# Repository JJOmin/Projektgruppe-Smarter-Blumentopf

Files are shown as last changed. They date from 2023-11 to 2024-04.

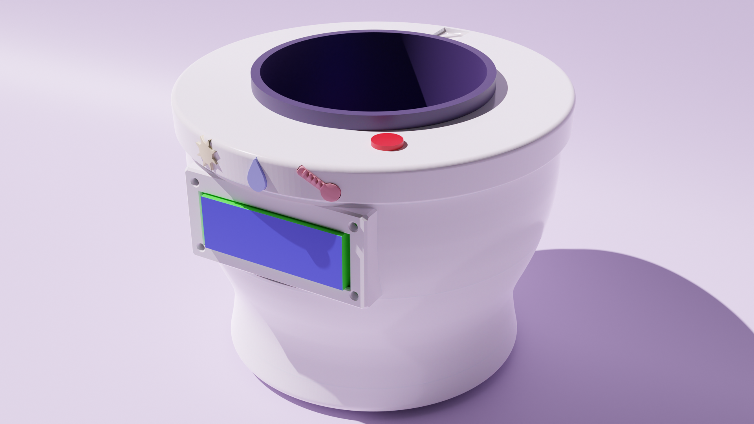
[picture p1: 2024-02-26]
3dModel/gerendert.png

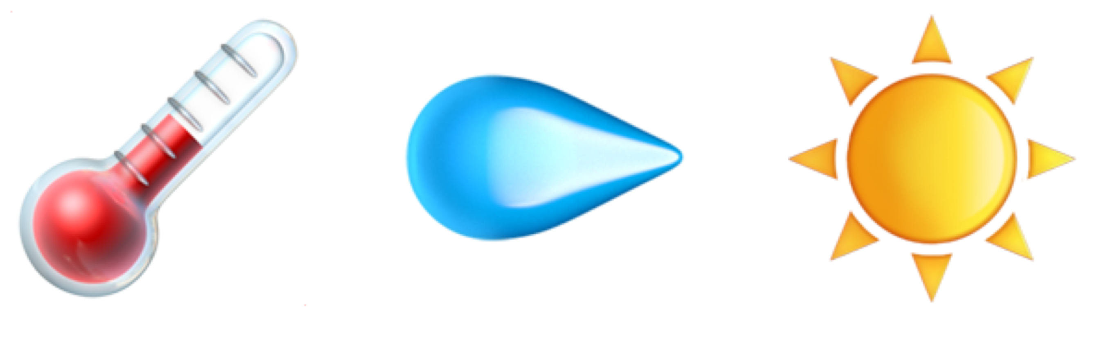
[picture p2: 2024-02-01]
3dModel/Bildschirmfoto 2024-01-30 um 16.26.23.png

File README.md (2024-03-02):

# Projektgruppe-Smarter-Blumentopf

**Projektbeschreibung:** Dieses Projekt konzentriert sich auf die Entwicklung eines intelligenten Blumentopfes, der durch eine Begleit-App gesteuert wird. Das Ziel ist es, eine nachhaltige und effiziente Bewässerung für Pflanzen zu ermöglichen, während gleichzeitig verschiedene Sensoren die Bedingungen der Pflanze überwachen. Programmablauf [hier](https://github.com/JJOmin/Projektgruppe-Smarter-Blumentopf/blob/44800ab2f6299ea2662f18130984cc1ef9804382/ESP32/README.md)

**Gruppenmitglieder:** 
[@Leo](https://github.com/JJOmin) [@Anna](https://github.com/Discovery1701A) [@Enis](https://github.com/NisVison) [@David](https://github.com/DaveBue) [@Sam](https://github.com/hystics)
  
## Guides
- ESP32 In Betriebnahme [hier](https://github.com/JJOmin/Projektgruppe-Smarter-Blumentopf/tree/c79d338f0dc577e0411f519bfa427959de9283d4/Guides)
  
## Programme
- Thonny IDE für MicroPython und ESP32 [hier](https://thonny.org/)
- Wokwi Simulation des ESP32 [hier](https://wokwi.com/projects/334090875207418452)
- Silicon Labs Treiber für USB to UART [hier](https://www.silabs.com/developers/usb-to-uart-bridge-vcp-drivers?tab=downloads)

## Sensoren Programmierung
  - **Simulation mit Wokwi [hier](https://github.com/JJOmin/Projektgruppe-Smarter-Blumentopf/tree/fa86ac6914044866652e3fb7bb85e3baa563d3ce/ESP32/Wokwi%20Simulation%20von%20Sensoren)**
  - **Courcecode [hier](https://github.com/JJOmin/Projektgruppe-Smarter-Blumentopf/tree/fa86ac6914044866652e3fb7bb85e3baa563d3ce/ESP32/Wokwi%20Simulation%20von%20Sensoren)**
    - Temperatursensor DS18B20 ([@Enis](https://github.com/NisVison))
    - Display ([@Anna](https://github.com/Discovery1701A) & [@Enis](https://github.com/NisVison))
    - Helligkeitssensor ([@Sam](https://github.com/hystics))
    - Bodenfeuchtigkeitssensor ([@Anna](https://github.com/Discovery1701A) & [@Leo](https://github.com/JJOmin))

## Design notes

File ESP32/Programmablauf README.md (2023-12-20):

# Programmablauf ESP32

## Setup
    - MVC Initialisierung
    - Aufbau der Wifi Connection
    - JSON Daten vom Server laden (db.json & prototyp.json) --> im Model speichern

## Programm-Loop (60 mal die Sekunde)

### Sensoren Intervall (alle 5 Sekunden)
    - Lesen der Sensorwerte
    - Vergleichen mit den Grenzwerten des gewählten Profils
        - ggfs. Status ändern --> Status Change Function (siehe unten)
    - Speichern der Messwerte im Model
        
### Server Intervall (nach 5 gemessenen Werte)
    - JSON Daten vom Server laden (prototyp.json) --> im Model speichern
        - ggfs. Änderungen für Name & Profil übernehmen
            - Bei Profiländerung: Neues Profil aus der db.json laden & Grenzwerte aktualisieren
    - Messwerte des Sensoren Intervalls mitteln
    - gemittelte Werte dem Log in der "prototyp.json" anhängen
    - "prototyp.json" auf dem Server überschreiben
    - Messwerte des Sensor Intervalls im Model zurücksetzen
    
### Button Pressed?
    - Wenn der Button gedrückt wird: Ausgabe der aktuellen Werte auf dem Display
    
### Status Change
    - LEDs Aktivieren/Deaktivieren
    - ggfs. Pumpe für kurze Zeit aktivieren
    - JSON Daten vom Server laden (prototyp.json)
    - Status in "prototyp.JSON" ändern
    - "prototyp.json" auf dem Server überschreiben

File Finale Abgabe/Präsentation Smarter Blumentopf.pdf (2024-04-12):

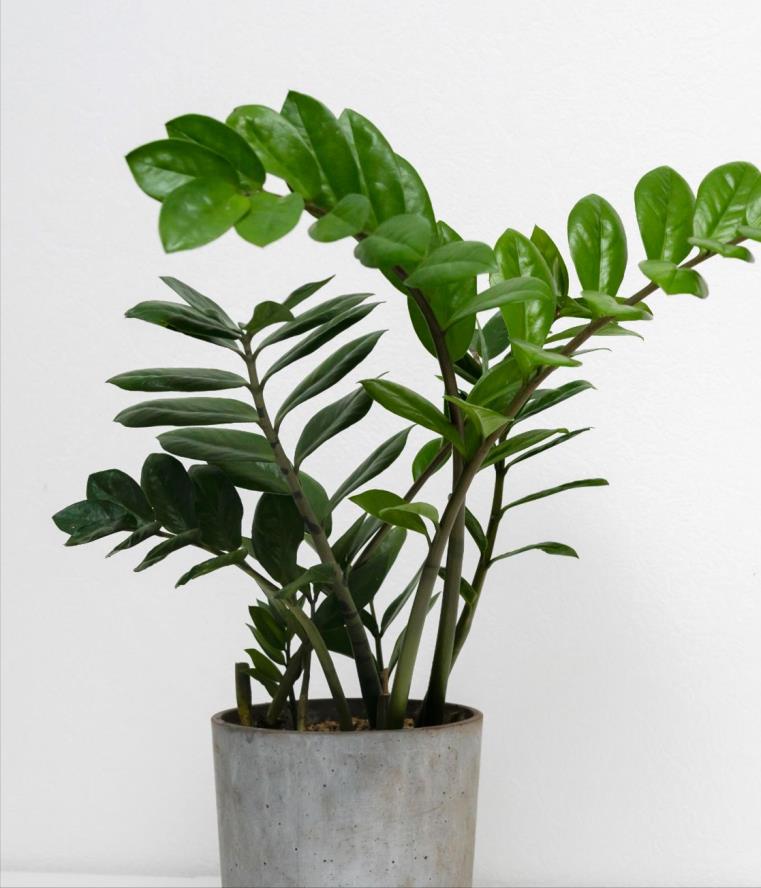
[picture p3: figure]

# Projektgruppe Interaktive Medien

beiProf. Dr. Maria Rauschenberger
ws 2023/24

Gruppe “Smarter Blumentopf”
von Enis Inep, David Bünnagel, Anna Rieckmann, Leonhard Tilly und Sarah Bokern

- Projektbeschreibung
- Ideenfindung
- HCD-Prozess – Aufbau, Umsetzung und Implementierung
- Umsetzung des Projektes
- Hardware
- Software
- Live-Demonstration
- Endergebnis
- Webinterface
- genutzte Arbeitsumgebungen
- Projektabschluss
- Quellen

## Präsentationsinhalt

## Projektbeschreibunginteraktive medien

- Konzeption und Entwicklung interaktiver
Medienprodukte
- Bedürfnisse und Verhaltensweisen von potenziellen Nutzern berücksichtigen
- Umsetzung mit HCD-Prozess
- Prototypgestaltung nach Interaktivität

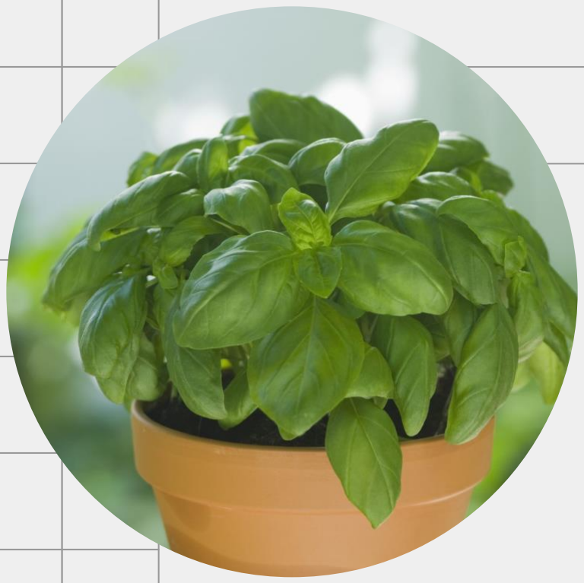
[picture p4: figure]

## Entstehung der grundidee

Ideenfindung

- Idee durch persönliche Erfahrungen: Basilikum stirbt sehr schnell
- Weiterführung: Was kann man dagegen tun? Gibt es eine technische Lösung?
- Folge: Recherche über "smarte" Blumentöpfe

## Recherche aktueller Projekte

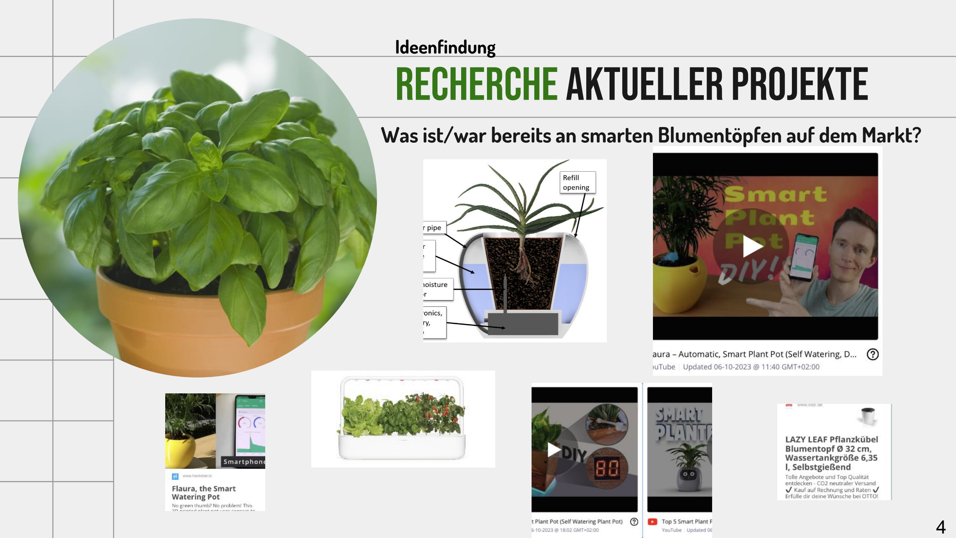
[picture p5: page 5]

Ideenfindung

Was ist/war bereits an smarten Blumentöpfen auf dem Markt?

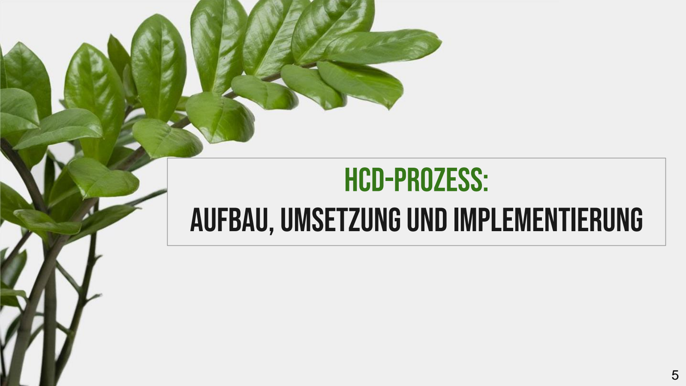
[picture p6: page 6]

## HCD-Prozess: aufbau, umsetzung und implementierung

## Erster entwurf: des blumentopfes

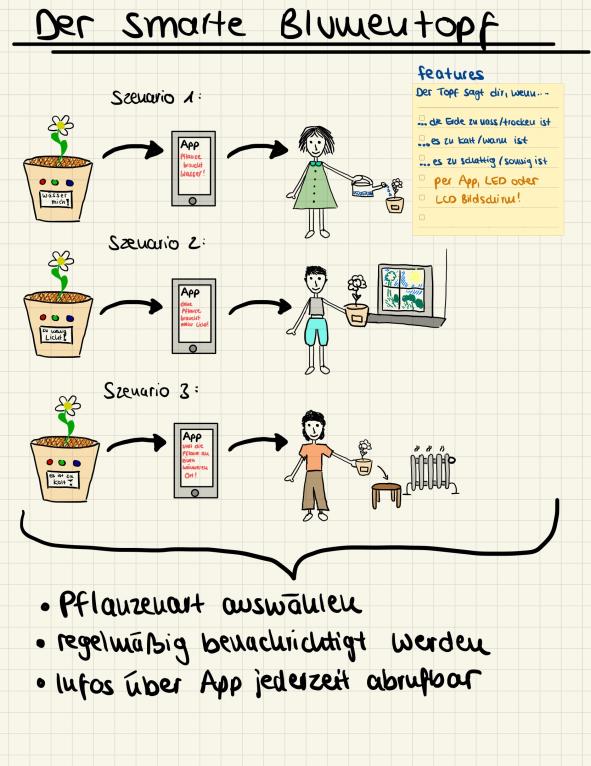
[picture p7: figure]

- Licht-, Temperatur- und Feuchtigkeitssensoren
- Auswählbare Pflanzenarten und Informationen zu idealen Haltungsverhältnissen
- Information durch App, LEDs und Display abrufbar

HCD-Prozess

## HCD-Prozess: aufbau und umsetzung

Aufbau der Semesterorganisation auf Grundlage des HCDs

Einteilung HCD in 2 große Phasen ("Teilabgabe" und "Endabgabe")

2 Fragebögen entworfen und ausgewertet

Auswertung, Implementierung, testen und erneute Befragung

## HCD-Prozess: UMFRAGE

Umfrage 1:
- Zielgruppe ist vergesslich
- Automatisierung (insbesondere Bewässerung)
- Steuerung über APP

Umfrage 2:
- LED Farben & Icons bestimmt
- Blinken vermeiden

Basierend auf Umfrage 1, Fragen 8/12/15/16/17, Umfrage 2, Fragen 5/6/7

- einfache Lösungen zur Haltung von Pflanzen
- Automatisierung, wenn niemand Zuhause ist
- Erinnerungen zur Pflege
- Erstellung von Pflanzenprofilen

## Persona grundprofil

profil
- Durchschnittsalter: 28 Jahre
- besitzt bereits Pflanzen
- berufstätig

charaktereigenschaften
- kann mit einfachen Problemen gut umgehen
- niedrige Frustrationstoleranz

wünsche

Stärken
- starke Technikaffinität

HCD-Prozess

- Vergesslichkeit

schwächen

9

## Entwicklungsziele

HCD-Prozess

- Effiziente Lösungen, die an den Nutzer angepasst sind

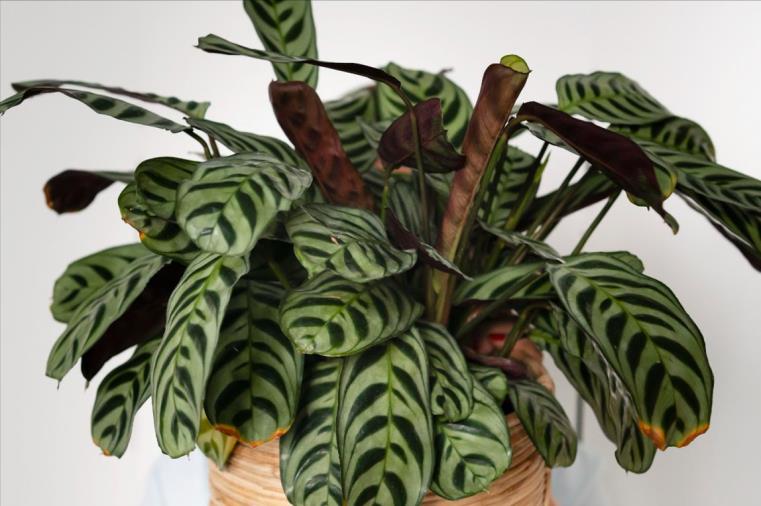
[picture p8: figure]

- Technische Unterstützung der Pflanzenpflege
- Anregung zur Verbesserung der Pflegeroutine
- Abnahme der Bewässerung

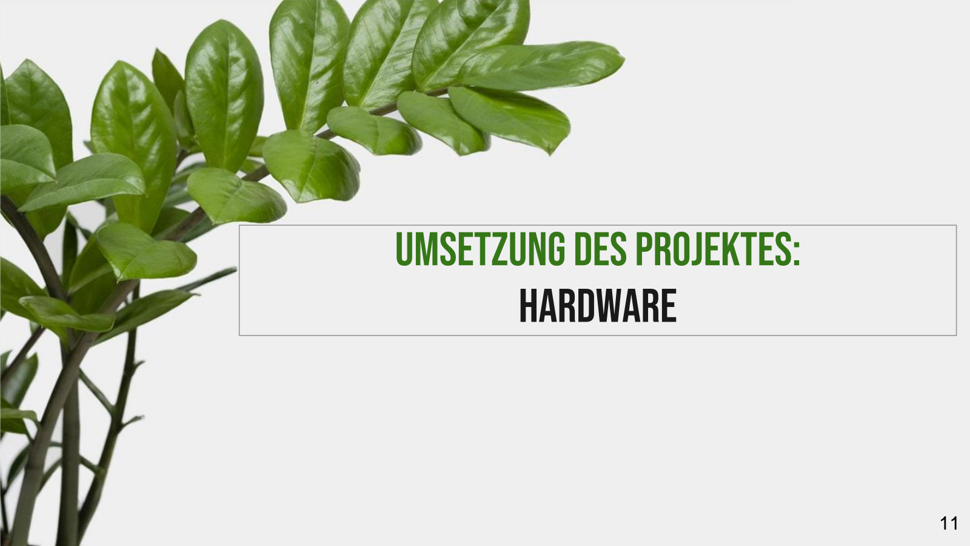
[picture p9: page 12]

## Umsetzung des projektes: hardware

## Hardware

Umsetzung des Projektes

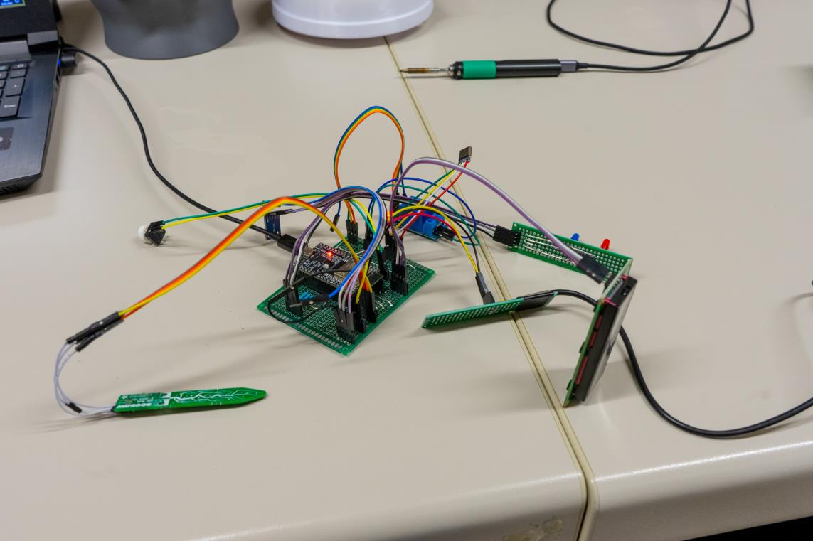
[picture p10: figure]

## Hardware-schaltplan

Umsetzung des Projektes

## Hardware

## - bauteile

Bauteile | Bezeichnung
Prozessor | ESP32 V2 WROOM
Bodenfeuchtigkeits -sensor | Adafruit STEMMA Soil Sensor -I2C Capacitive Moisture Sensor - JST PH 2mm
Temperatursensor | ds18b20
Helligkeitssensor | GY -302 BH1750
Display | DEBO LCD 16X2 BL
Relais | Songle sdr -05vdc -sl -c
Pumpe | PDM5 D916 5V

Umsetzung des Projektes

## Hardware - Blender

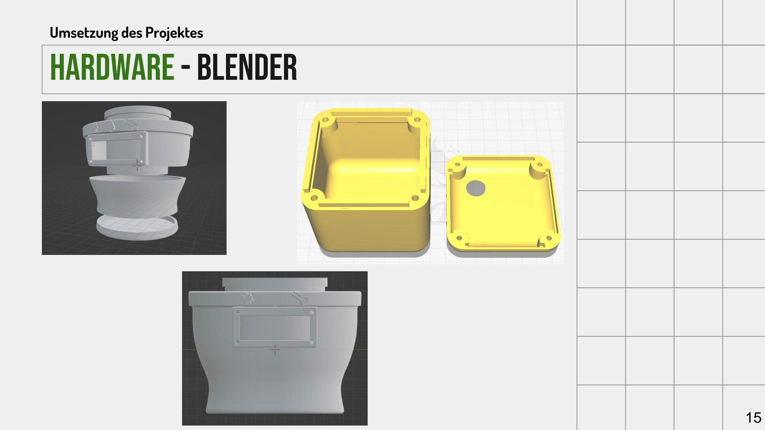
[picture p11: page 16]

Umsetzung des Projektes

## Hardware – Ausgabe

Umsetzung des Projektes

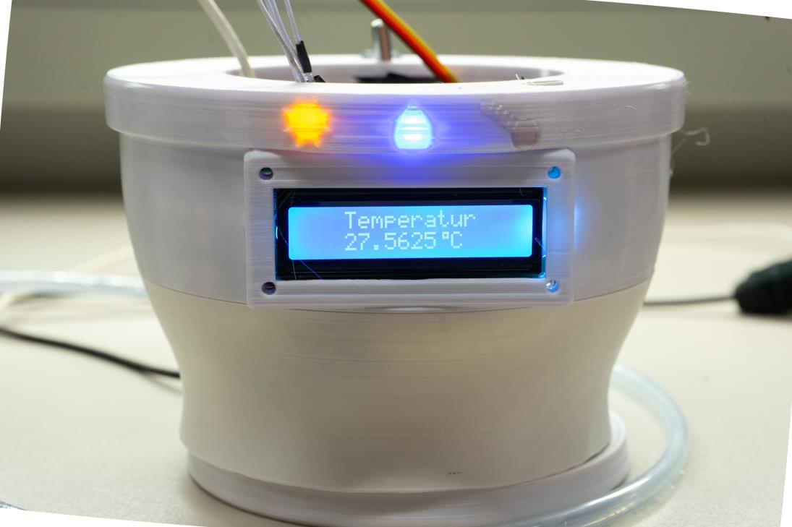
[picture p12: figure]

## Umsetzung des projektes: software

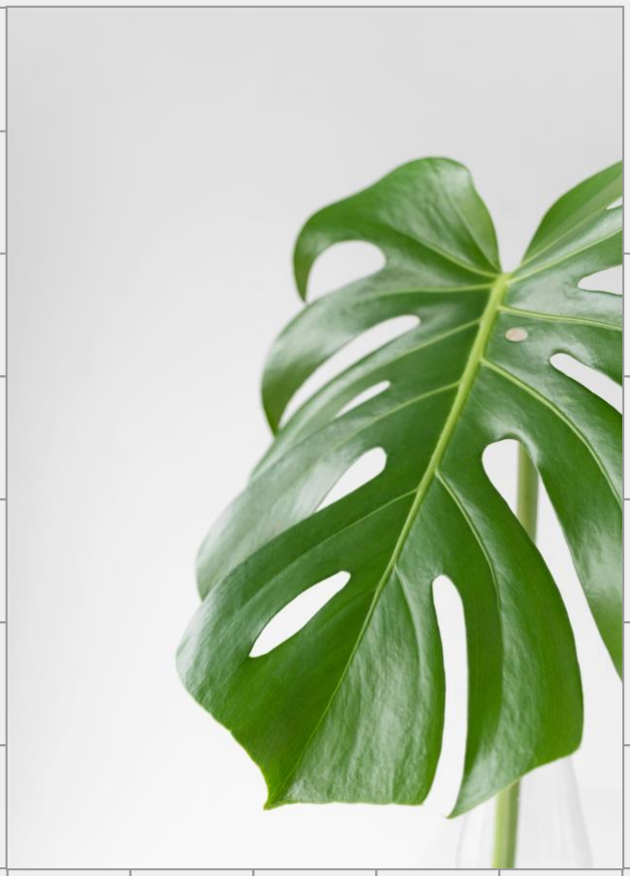
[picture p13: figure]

software • Arbeitsumgebung in Thonny • Umsetzung in Python, basierend

auf OOP

- Kommunikationsstruktur zwischen ESP, Hardware und
Webserver/Website?
- Aufbau des Programmes nach dem MVC

-Modell?

Umsetzung des Projektes

## Software: klassenstruktur

Umsetzung des Projektes

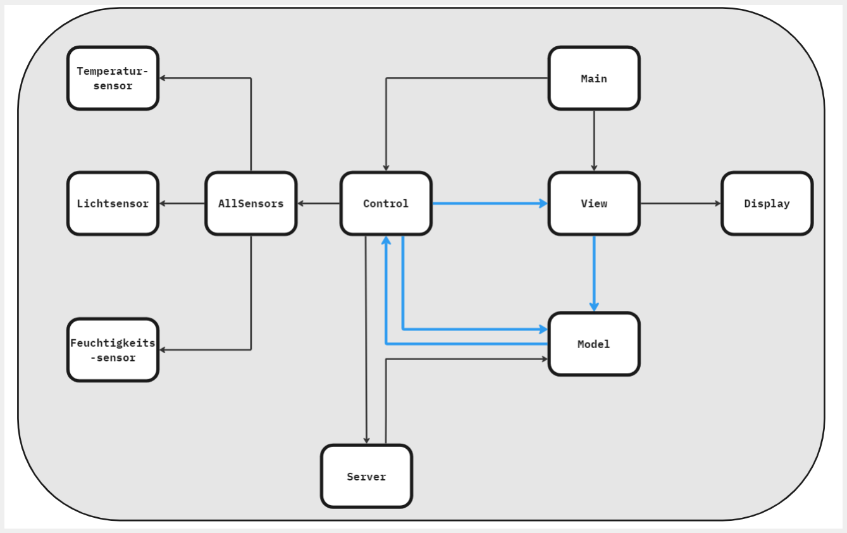
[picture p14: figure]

## Software: kommunikationsstruktur

Umsetzung des Projektes

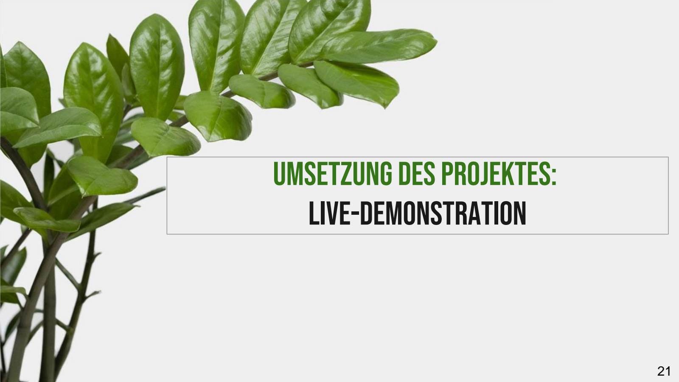
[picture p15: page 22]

## Umsetzung des projektes: Live-Demonstration

## Endergebis: der blumentopf

- Messung von Licht, Temperatur und Bodenfeuchtigkeit

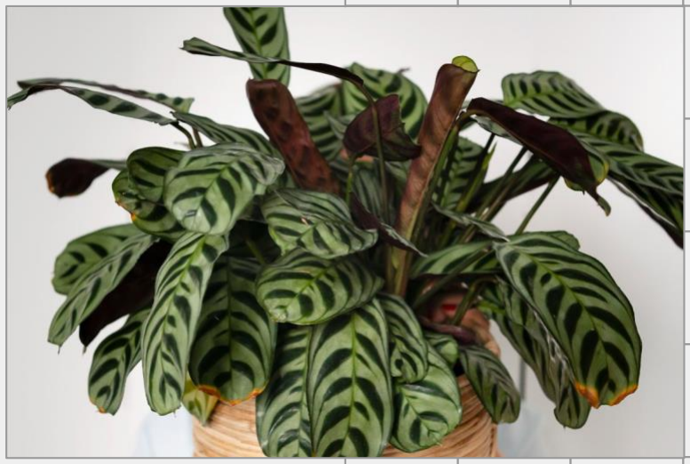
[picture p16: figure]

- Bewässerung
- Status LEDs
- Button zur Ausgabe auf dem Display
- Website zur Einsicht von Daten und zur Bearbeitung und Einstellungen von Profilen

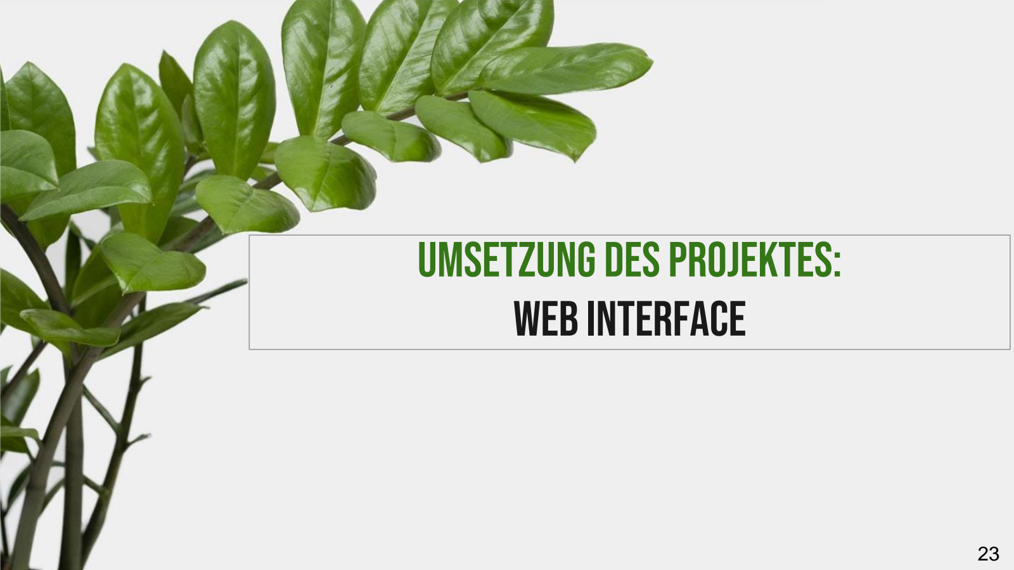
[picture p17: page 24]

## Umsetzung des projektes: Web interface

## Webinterface: browseransicht

Umsetzung des Projektes

## Webinterface: browseransicht

Umsetzung des Projektes

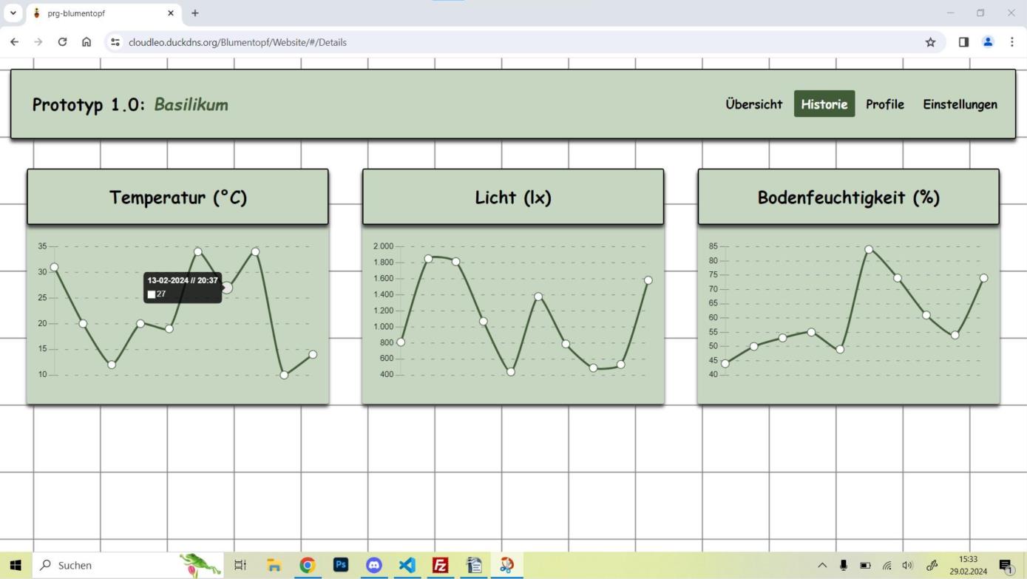
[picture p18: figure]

## Webinterface: browseransicht

Umsetzung des Projektes

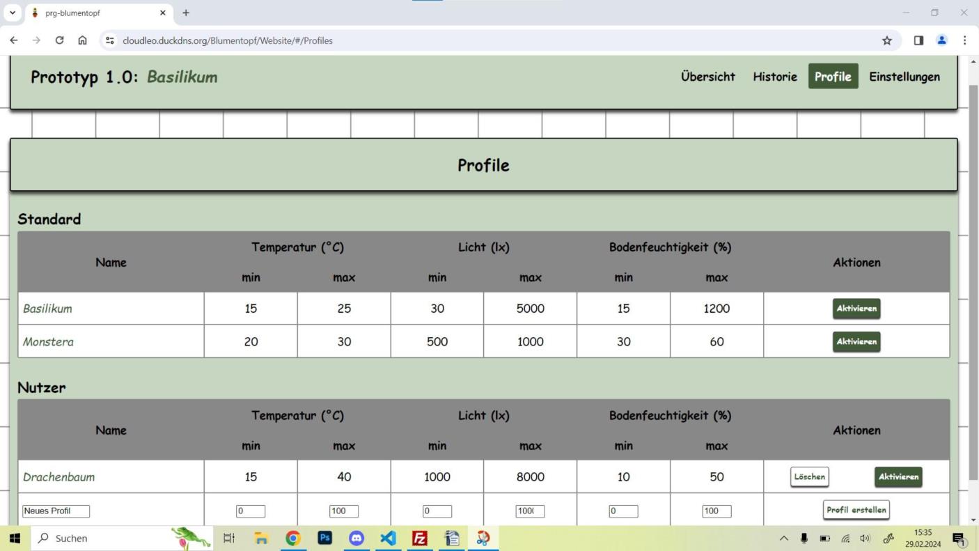
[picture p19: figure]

## Webinterface: browseransicht

Umsetzung des Projektes

## Webinterface: browseransicht

Umsetzung des Projektes

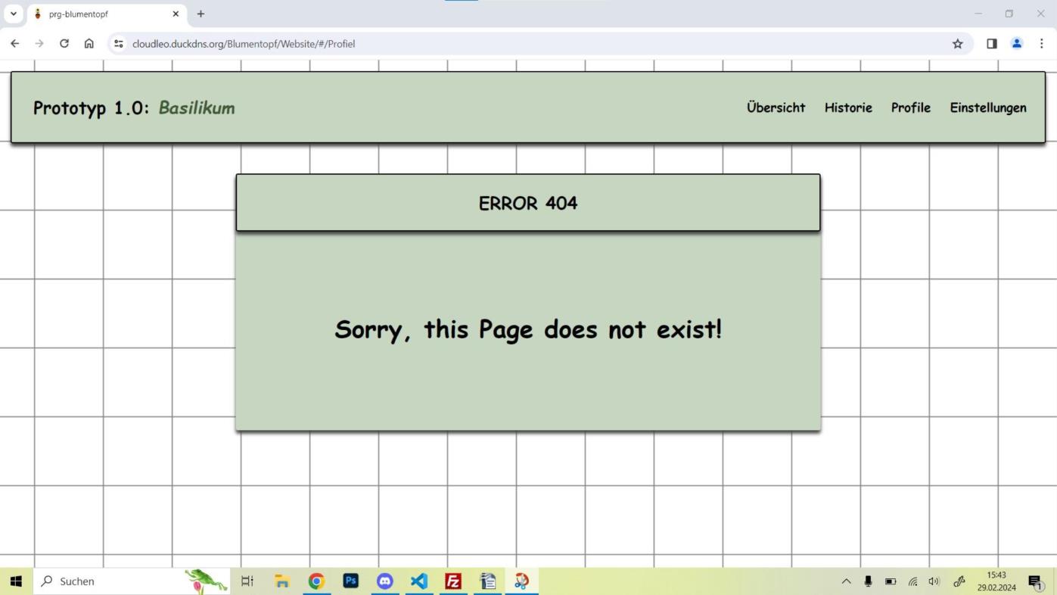
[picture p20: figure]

## Webinterface: Mobile ANsicht

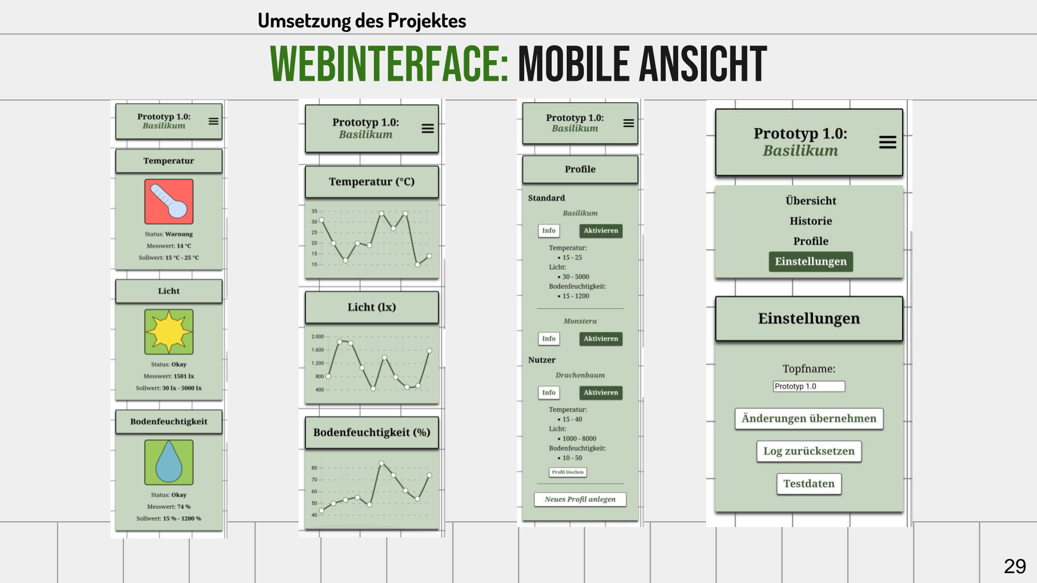
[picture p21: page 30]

Umsetzung des Projektes

## Umsetzung des projektes: arbeitsumgebungen

## arbeitsumgebungen

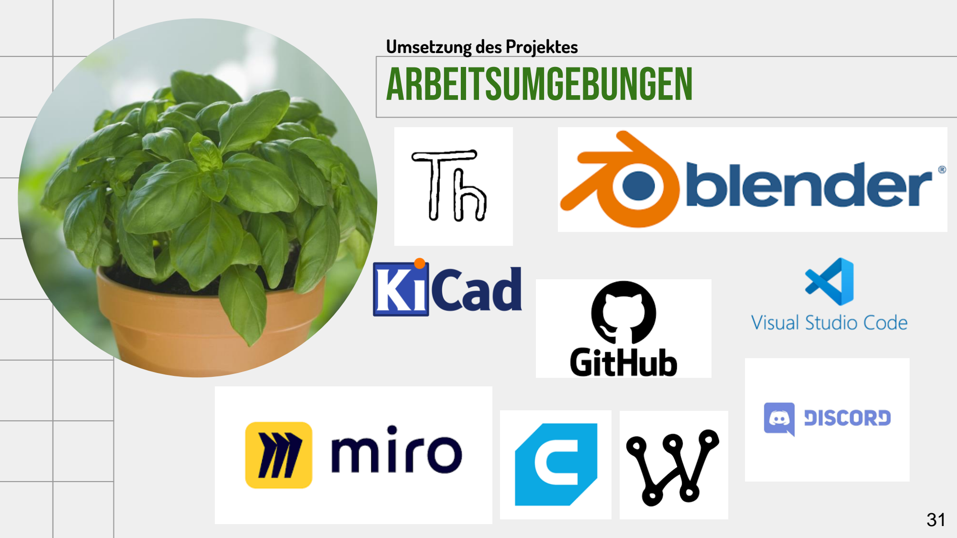
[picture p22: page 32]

Umsetzung des Projektes

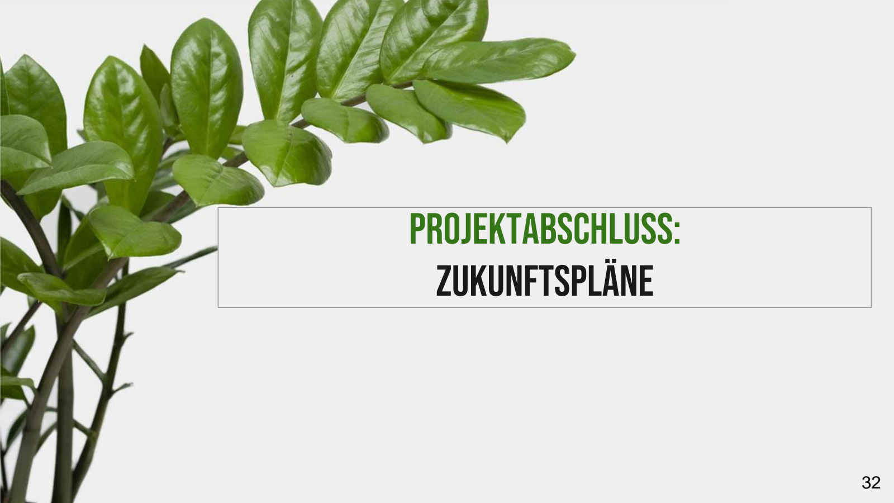
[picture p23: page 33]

## Projektabschluss: zukunftspläne

## zukunftspläne–zukünftigeerweiterungen

Mögliche Ideen:

- Implementation eines Akkus
- Wetterdatenbankeinbindung (Interpretation der Daten)
- Datenbank für verschiedene Pflanzen
- „Grow-A-Plant“-Modus zum Hochziehen einer Pflanze
- Sleep/Energy-Saving-Mode

Projektabschluss

## Zukunftspläne-version 2.0

- Pumpenprotokoll in
JSON
- Web-App Integration
- Stand-Alone-System
ohne separaten Server
- Pumpensteuerung über
Website/App
- Pushnachrichten auf Handy und Web
- ID für ESP, Login und
Nutzerprofile (Datenbank)
- Lautsprecher
- UV-Lampe, LED-Streifen
- besseres Display (Touch?)

Umsetzung des Projekts

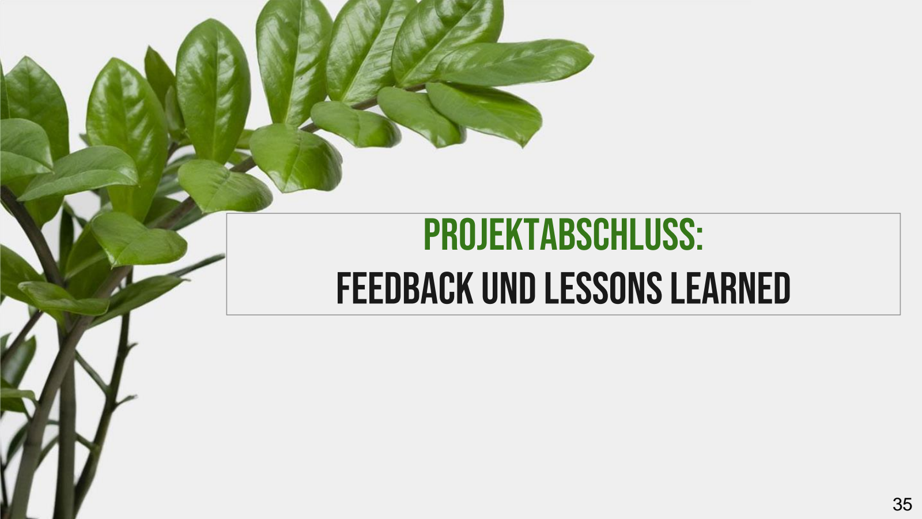
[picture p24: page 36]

## Projektabschluss: Feedback und Lessons Learned

## Feedback –Evaluation der Zusammenarbeit

- Kommunikation, Umgang mit Konflikten
- Organisation der Aufgaben
- Projektleitung
- Semesterplanung

Projektabschluss

## lessonslearned

Projektabschluss

## Feedback – wünschefür die zukunft

Was wünschen wir uns voneinander, wenn wir von hier aus weitermachen würden?

- Umsetzungsstruktur, klare Definition von Aufgaben, Bearbeitung jedoch zusammen
- feste Deadlines und Ziele, wenn wir nicht studieren würden
- bessere Planbarkeit der eigenen Zeit -> einfachere Selbstorganisation
- intrinsische Motivation, ohne Projektleitung zusammenzuarbeiten

Projektabschluss

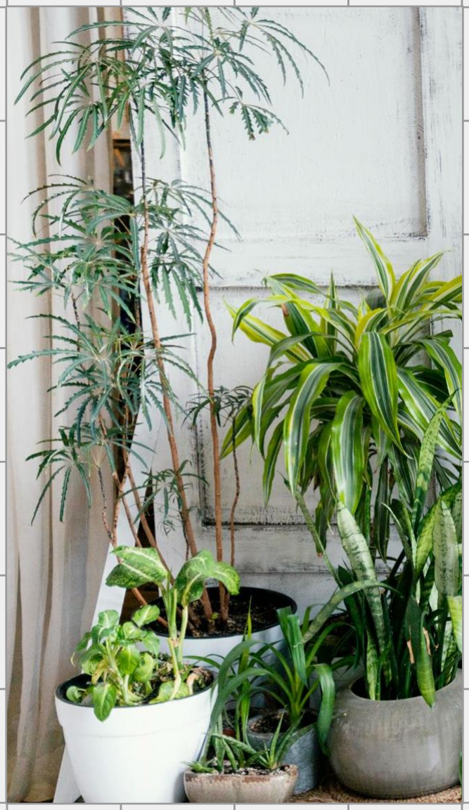
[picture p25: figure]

## Quellen –seite 1

Zur Hardware:
https://eckstein-shop.de/Adafruit-STEMMA-Soil-Sensor-I2C-Capacitive-Moisture-Sensor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 (https://eckstein-shop.de/Adafruit-STEMMA-Soil-Sensor-I2C-Capacitive-Moisture-Sensor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)

https://www.amazon.de/dp/B0B76YGDV4?ref_=cm_sw_r_apin_dp_6MJYBTXBB2EM95Y4J3JD&language=de-DE&th=1

Informationen zum ESP: (https://www.amazon.de/dp/B0B76YGDV4?ref_=cm_sw_r_apin_dp_6MJYBTXBB2EM95Y4J3JD&language=de-DE&th=1)
https://docs.micropython.org/en/latest/esp32/quickref.html

https://github.com/espressif/esptool/releases/tag/v4.6.2

https://micropython.org/download/#esp32

https://www.instructables.com/Getting-Started-With-ESP32-on-a-Mac/

https://randomnerdtutorials.com/projects-esp32/

## Quellen –seite 2

Infomationen zum Code:
https://randomnerdtutorials.com/micropython-oled-display-esp32-esp8266/

https://thonny.org/

https://randomnerdtutorials.com/micropython-wi-fi-manager-esp32-esp8266/

https://randomnerdtutorials.com/micropython-ds18b20-esp32-esp8266/

https://wokwi.com/projects/new/micropython-esp32

https://microcontrollerslab.com/i2c-lcd-esp32-esp8266-micropython-tutorial/

Infomationen zur Website:
https://jqueryui.com/

https://coolors.co/contrast-checker/112a46-acc8e5

Präsentationslayout:

## Quellen –seite 3

Inspirationen smarter Blumentöpfe: https://vivien-muller.fr/lua#super-simple-app

https://img.thingiverse.com/cdncgi/image/fit=contain,quality=95/https://cdn.thingiverse.com/assets/71/50/83/30/e7/large_display_Sketch.PNG (https://img.thingiverse.com/cdn-cgi/image/fit=contain,quality=95/https:/cdn.thingiverse.com/assets/71/50/83/30/e7/large_display_Sketch.PNG)

https://www.youtube.com/watch?v=rHHFL17ncnc, Flaura automatic smart plant pot

https://www.youtube.com/watch?v=fNg8nQjqIq4, how to make a smart plant pot

https://www.youtube.com/watch?v=5_nwNWQxWsc, top 5 smart plant pots

https://www.otto.de/p/lazy-leaf-pflanzkuebel-blumentopf-o-32-cmwassertankgroesse-6-35-l-selbstgiessend-S0U2M0XW/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 0A0CA, (https://www.otto.de/p/lazy-leaf-pflanzkuebel-blumentopf-o-32-cm-wassertankgroesse-6-35-l-selbstgiessend-S0U2M0XW/) Lazy leaf plant pot

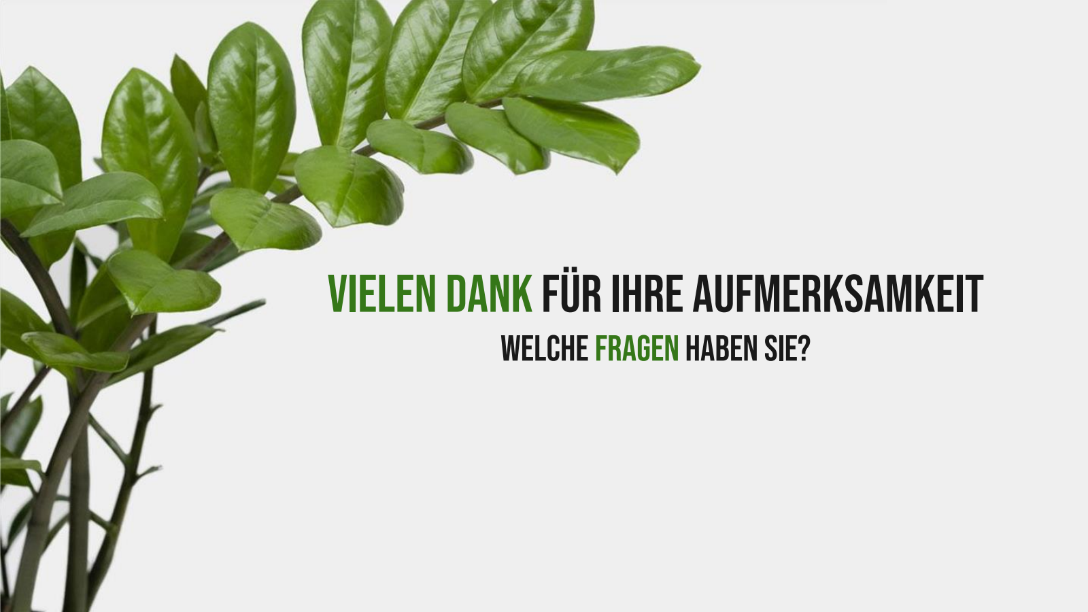
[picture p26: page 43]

## vielen dank für ihre aufmerksamkeit

Welche Fragen haben SIe?

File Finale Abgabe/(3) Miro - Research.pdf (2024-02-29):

# Organisation /Overview

randomnerdtutorials.com

## 160+ ESP32 Projects, Tutorials and Guides with Arduino IDE | Random Nerd Tutorials

Discover all our ESP32 Guides with easy to follow step-by-step instructions. Each tutorial includes circuit schematics, source code, images and videos.

randomnerdtutorials.com MicroPython: DS18B20

## Temperature Sensor with ESP32 and

## ESP8266 | Random Nerd Tutorials

DS18B20 Temperature sensor with ESP32 and ESP8266 using MicroPython. Learn how to read temperature from one or multiple sensors and build a web server to display sensor readings.

# Marc Hassenzahl

de.wikipedia.org Marc Hassenzahl - Wikipedia

Marc Hassenzahl (* 1969) ist ein deutscher, promovierter Psychologe und seit 2016 Professor für Ubiquitous Design/Erlebnis und Interaktion am

Institut für Wirtschaftsinformatik der Universität Siegen. Im Jahr 2006 promovierte Marc Hassenzahl an der Tech… https://randomnerdtutorials.com/micropython-esp32-esp8266-vs-code-pymakr/

# Blynk alternativen -Benachrichtigungen mit Firebase Cloud und eigener App (teste

# gerade ob das LoFi geht)

wokwi.com New MicroPython on

ESP32 Project - Wokwi Simulator

Create a new MicroPython on ESP32 simulation project, run it in your browser and share your code and schematics.

# Research Links + Bilder

## docs.micropython.org Quick reference for the

# ESP32 - MicroPython latest documentation

## The Espressif ESP32 Development Board

(image attribution: Adafruit). Below is a quick reference for ESP32-based boards.

## If it is your first time working with this board it may be useful to get an

## overview of the microcontroller: See the corresponding se…

## github.com

# Release Version 4.6.2 · espressif/esptool

## Bug Fixes ESP32-H2, ESP32-C6: Fixed

byte order in MAC address. C900: Too much data: Fixed occasional compressed upload failures. CH9102F USB-to-UART: Suggest installing new

serial drivers if writi...

# micropython.org

# MicroPython - Python

# for microcontrollers MicroPython is a lean and efficient

# implementation of the Python 3 programming language that includes a

# small subset of the Python standard library and is optimised to run on microcontrollers and in constrained

environments.

Pymakrv2.22.5

# Pymakrv 2.22.5 VSCode Erweiterung

www.instructables.com Getting Started With

## ESP32 on a Mac

Getting Started With ESP32 on a Mac: About ESP32 ESP32 is a low cost and low power system on a chip microcontroller with integrated Wi-Fi & dual-mode Bluetooth. ESP32 is created and

developed by Espressif Systems, a Shanghai-based Chinese company, a…

# thonny.org

# Thonny

# Thonny 4 is dedicated to Ukraine

fighting the Russian invasion. | Please
support Ukraine! | From 2014 to 2018

# the main development of Thonny took place in Institute of Computer Science of University of Tartu, Estonia. Since September 2018 development of…

# randomnerdtutorials.com

# MicroPython: Wi-Fi Manager with ESP32 and ESP8266 | Random Nerd Tutorials

# Use Wi-Fi Manager with ESP32 and ESP8266 using MicroPython firmware. Wi-Fi Manager allows you to connect

# your ESP32 to different Access Points

(different networks).

microcontrollerslab.com
I2C LCD with ESP32 and
ESP8266 using MicroPython

Interface I2C LCD with ESP32 and ESP8266 using MicroPython examples to display text messsages and custom characters

# jqueryui.com

# jQuery UI

# jQuery UI is a curated set of user

interface interactions, effects, widgets,

# and themes built on top of the jQuery JavaScript Library. Whether you're building highly interactive web applications or you just need to add a date picker to a form control, j…

randomnerdtutorials.com MicroPython: OLED

## Display with ESP32 and ESP8266 | Random Nerd Tutorials

This guide shows how to use the 0.96 inch SSD1306 OLED display with ESP32 or ESP8266 using MicroPython firmware. Learn how to display a 'Hello, World' message and much more.

# eckstein-shop.de

# Adafruit STEMMA Soil Sensor - I2C Capacitive Moisture Sensor -Arduin, 9,95 €

# Arduino Distributor in Germany This design is superior with a capacitive measurement. Capacitive

measurements use only one probe,

# don't have any exposed met

# coolors.co

# Color Contrast Checker - Coolors

# Calculate the contrast ratio of text and

background colors.

# www.amazon.de

# FREENOVE I2C LCD 1602 Module, New Type IIC

TWI Serial 16x2 Display,

# Compatible with Arduino Raspberry Pi Pico ESP32 ESP8266

# FREENOVE I2C LCD 1602 Module, New

Type IIC TWI Serial 16x2 Display,

# Compatible with Arduino Raspberry Pi Pico ESP32 ESP8266

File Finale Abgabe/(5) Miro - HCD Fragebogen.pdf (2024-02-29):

# Design finalisieren Interaktion klar definieren und verfeinern Leuchtet das immer -> Display: Nein

Es wird nicht erwartet Finales Produkt.
Wichtig ist das wir Konkrete User Interaktion einbinden und wirklich umsetzen. Wichtig einbauen der User Interaktion

# Finaler Pitch/Präsentation sollte Professioneller sein (business casual, vorbereitet usw.) Darstellung nicht nur in in Farben sondern auch mit Symbolen oder Text

# Weitere mögliche optionen nach der Abgabe

Möglichkeit unser Projekt als Demo vorstellen auf einer Konferenz HCI, Wissenschaftliches Paper dazu, aufbereiten und einreichen. Exkursion.

# Feedback Rauschenberger zu Zwischenbericht

# Aktuelle aufgaben:

# Lessons Learned notieren (alle)

# HCD 2.0 vorbereiten; Fragebogen usw erstellen


# Design Pumpe und Reservoir (3D + Druck) Integration der Icons in das 3D Model (3D + Druck) Elektronik; Pumpe, LEDs anbinden Datenbank auf ESP!? -> wenn Server DB Offline, trotzdem sollen LEDs Funktionieren (bisl Json Aktion, evtl LEDs bei Start kurz alle an)

# Konkrete User Interaktion einbinden und wirklich umsetzen!!!

# Präsentation vorbereiten PPP & im Miro zusammentragen (alle) Icons auf die Website Graphische Darstellung der Messwerte

# HCD 2.0 - Fragebogen Entwurf Wie soll interaktion passieren Welches Design erleichtern Interaktion und Informationsvermittlung (LED Icons)

# Konkrete Fragen:

Design;

Icons passend wie aktuell? Farben für Icons und LEDs so richtig? Anordnung der Icons Wo? (Oberer rand?) Blinkende LEDs für Info des "Füllstandes" nervig oder gut? Nachtmodus für Display, LEDs usw notwendig Von und bis wann? Farbe des Topfes Design des Topfes? Modern, Dezent, Minimalistisch, Quadratisch oder Rund? Einfach ne richtung, aus stock Fotos

Website/App;

# Home Message Box? Gewollt oder nervig (auch als Log/history) Protokoll Manuelle Fernsteuerung der Pumpe (also menge in ml variabel?)

### Basics zu Accessibility bezogen auf den Blumentopf:

https://www.din.de/de/meta/suche/62730!search?query=Mensch-System-Interaktion (https://www.din.de/de/meta/suche/62730!search?query=Mensch-System-Interaktion)
Kurzfassung im Buch rechts ab Seite 38ff!!!!

### Darstellung im Web:

- Einstellung von Schriftgrößen/Darstellungsgrößen
- Möglichkeiten schaffen, ranzuzoomen ohne dass etw. verzerrt wird
- minimales und effizientes Design
- alles klar beschriftet, auch Icons/Grafiken
- Schriftart mit Serifen mit 1,5 Zeilenabstand lässt sich am ehesten lesen
- Schriftart wählen, die auch mit Lese/Rechtschreibschwäche gut zu lesen ist (Beispiel: Comic Sans)
- WCAG Standards für Farbkontraste
- Farben wählen, die auch Farbenblinde gut unterscheiden können
- schwarz und weiß Kontraste vermeiden; schwer zu lesen für Farbenblinde, Dyslexie, Konzentrationsstörungen
- NUR Kommunikation durch Farben vermeiden, immer beschriften
- Klare Navigationsstruktur und Symbolik

### Bezogen auf Blumentopf:

- schlichte Topffarbe, von der sich die LEDs abheben können
- kein blinken (Informieren, nicht ablenken)
- Display Ausgaben so gestalten, dass ein Wort nicht nachrückt (schwer zu lesen)
- Zustände werden oft auf Geräusche validiert - eventuell doch Geräusche mit einbringen?

Grundlagen zu Usability, reinschauen als Referenz!!!!!!!

Fragen von Enis/Leo:

- Sind die Icons leicht verständlich und repräsentativ für die entsprechenden Funktion? => Ja, aber farblich voneinander trennen, und unter den Icons Beschriftungen anfügen
- Die Farben für Icons und LEDs sollten intuitiv sein. Zum Beispiel könnten Grüntöne für einen gesunden Zustand stehen. => grün und rot -> aber wie macht man das bei Farbenblindheit? hohen Kontrast beachten
- Blinkende LEDs könnten visuell nützlich sein, solange sie nicht zu aufdringlich sind(ich sag mal blickfrequenz sollte nicht zu schnell sein) => lt. Guidebook kann blinken sehr ablenkend sein, eventuell nicht durchgehend? Nur alle paar Minuten mal? Blinkfrequenz wär auch gut
- Ein Nachtmodus für Display, LEDs & Controller könnte sinnvoll sein, (vllt anpassbar vom Nutzer individuell?) => Reicht nicht auch einmal täglich den Status zu kriegen und sonst einen "permanenten" Nachtmodus zu haben? -> Benachrichtigungszeit individuell einstellbar?
- Bei der Farbe des Topfes kann man sich fragen ob, Farben nach persönlichen Vorlieben oder Naturtöne wie Grün oder Braun. => Würde sogar braun sagen, um den Kontrast zwischen LEDs und Blumentopf hoch zu halten
- Form des Topfes Modern, Dezent, Minimalistisch, Quadratisch oder Rund? (man könnt hier noch die Grundregeln für ein design mit einbeziehen. Gelernt Computergrafiken) => mit beachten: aktueller Trend/wie sehen durchschnittliche Blumentöpfe heute so aus? Was wird gekauft?
- Message Box könnte nützlich sein für, Informationen, Warnungen oder Aktualisierungen, kann aber auch nerven oder Aufdringlich sein. => ggf. nur gemeinsam mit LED Statusausgaben anzeigen lassen?
- Protokoll, damit ist vermutlich die Datenprotokollierung gemeint? Wenn ja könnte sie sehr nützlich sein. (aber denke ich an Otto Normalverbraucher, der würde niemals gucken.)
- Manuelle Fernsteuerung, wäre nützlich denke ich

Platzierungen: Unteres Drittel des Topfes für LEDs und Display -> Größe und Breite des Blumentopfes mit beachtet; bessere Sichtbarkeit

# HCD 2.0

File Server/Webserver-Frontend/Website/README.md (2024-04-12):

# Link zur Website:
  - https://cloudleo.duckdns.org/Blumentopf/Website/#/

# Vue.js Website (genutztes JS Framework):
  - https://vuejs.org/

# Vue.js Tutorial für Visual Studio Code:
  - https://code.visualstudio.com/docs/nodejs/vuejs-tutorial

# Vue Router (für Navigation auf der Website):
  - https://router.vuejs.org/

# Chart.js für Vue.js (für Darstellung der Daten als Graph):
  - https://vue-chartjs.org/

# Gute Vue.js Tutorials:
  - https://www.youtube.com/watch?v=YrxBCBibVo0&list=PL4cUxeGkcC9hYYGbV60Vq3IXYNfDk8At1

# Kurzanleitung:

Vue.js, Vue Router und Chart.js wie auf der jeweiligen Website beschrieben mit dem
Node Package Manager (NPM) installieren.
Anschließend einmal "npm install" ausführen!
Am besten in Visual Studio Code noch die "Vue Language Features" Extension installieren ;)

Lokal hosten mit "npm run serve" funktioniert nicht, weil man vom localhost ja keine Zugriffsrechte
auf Leos Server hat.

Daher zum updaten der Live-Website "npm run build" ausführen und anschließend den Website Ordner
auf dem Server durch den dist Ordner ersetzen (diesen dann logischerweise wieder in Website umbenennen)
Assets wie die Icons müssen manuell ins assets Verzeichnis hinzugefügt werden (nur bei Änderung).

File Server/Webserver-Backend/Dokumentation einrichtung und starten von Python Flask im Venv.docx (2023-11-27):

Dokumentation einrichtung und starten von Python Flask im Venv

1. Venv zugreifen: source myflaskenv/bin/activate
2. App.py im venv starten: gunicorn -w 4 -b 192.168.178.59:5000 app:app
3. Beenden über „Control“ + „C“
4. Verlassen von venv: „Deactivate“
5. Aud app.py zugreifen im venv: nano app.py (speichern in nano mit conrtol + x und dann y, enter)
6. Code der app.py:

from flask import Flask, request

import json

import datetime

app = Flask(__name__)

@app.route('/Blumentopf/upload_data', methods=['POST'])

def upload_data():

if request.method == 'POST':

try:

data = request.get_json() # JSON-Daten von ESP32 erhalten

if data: # Überprüfen, ob gültige JSON-Daten erhalten wurden

current_time = datetime.datetime.now().strftime("%Y-%m-%d_%H-%M-%S")

file_name = f'received_data_{current_time}.json' # Eindeutiger Dateiname

with open(file_name, 'w') as file: # Daten in eine neue Datei schreiben

json.dump(data, file, indent=4)

return "Daten erfolgreich empfangen und gespeichert"

else:

return "Ungültige JSON-Daten erhalten"

except Exception as e:

return f"Fehler beim Verarbeiten der Daten: {str(e)}"

else:

return "Nur POST-Anfragen erlaubt"

if __name__ == '__main__':

app.run(host='192.168.178.59', port=5000) # Anpassen des Ports und der Host-Adresse nach Bedarf

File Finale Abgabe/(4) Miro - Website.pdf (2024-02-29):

Website PC


Website Mobile


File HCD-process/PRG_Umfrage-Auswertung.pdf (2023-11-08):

# Zusammmenfassung der Umfrageergebnisse

Zusammenfassung:

Die Vorstellungen der Befragten stimmen größtenteils mit unseren Überlegungen überein. Der smarte Blumentopf sollte für die Platzierung auf einer Fensterbank konzipiert werden. Ein wichtiges Feature, dass wir einbinden sollten ist ein automatisches Bewässerungssystem.
Profile für einzelne Pflanzen lohnen sich auf jeden Fall. Insbesondere für Monstera und Kakteen.

### 1. Alter der Befragten

Durchschnittsalter: 26,65 Jahre

Fazit:
Die Befragten sind größtenteils ungefähr in unserem Alter. Daher können wir davon ausgehen, dass sie vermutlich ein Smartphone besitzen und dieses bedienen können. Es werden keine Features für "Senioren" benötigt.

### 2. Wo wohnst du?

Etwa 50% wohnen in einer Wohnung. Der Rest teilt sich auf WG und Haus auf.

### 3. Besitzt du Pflanzen

80% antworteten mit "Ja"

Fazit:
Die Befragten besitzen ein Grundverständnis der Pflanzenpflege.

### 4. Welche Pflanzen besitzt du?

Die benannten Pflanzen lassen sich in drei Kategorien zusammenfassen:

### 1. Zimmerpflanzen 2. Kakteen 3. Kräuter

Fazit:
Es sind nur wenig Blumen unter den Pflanzen enthalten. Pflanzen, für die sich ein Profil lohnen würde:
- Monstera
- Orchidee
- Aloe Vera
- "Kaktus"
- Minze
Weitere Profile basierend auf unseren Überlegungen:
- Küchenkräuter (Basilikum, Rosmarin, Thymian)
- Kartoffeln
- Zwiebelarten (Zwiebeln, Frühlingszwiebeln, Knoblauch)
- Tulpen (oder sonstige Blumenzwiebeln)

### 5. Wieviele Blumentöpfe hast du?

Durchschnittswert: 14,61 Töpfe

Anmerkung:
Der Wert ist wegen einzelnen Ausreißern relativ hoch ausgefallen.

### 6. Wo steht der Blumentopf

Meistgenannten Orte:

### 1. Fensterbank (28) 2. Auf dem Boden (15) 3. Küche & Schlafzimmer (12)

Fazit:
Antworten passen zu unserer Überlegung, den smarten Blumentopf in Bezug auf Größe und Lichtsituation für die Platzierung auf der Fensterbank zu konzipieren.

### 7. Wie groß sind die Töpfe?

Meistgewählte Größen:
1. 10 cm - 20 cm (25)

### 2. kleiner als 10 cm (16)

3. 20 cm - 50 cm (16)

Fazit:
Auch diese Frage bestärkt uns in unserer Überlegung, den Blumentopf für die Fensterbank zu planen.

### 8. Vergisst du das gießen?

Der Großteil antwortete mit "Ja, manchmal".

Fazit:
Ein System mit automatisierten Gieß-Erinnerungen oder vllt auch eingebautem Bewässerungssystem lohnt sich.

### 9. Welche Pflanzen würdest du dir wünschen?

Topantwort: Monstera (6)

Anmerkung:
Hier gab es verhältnismäßig nur wenige Antworten.
Dafür wurden hier im Gegensatz zu Frage 4 viele Blumen genannt. Man könnte also überlegen, ob man mit dem smarten Blumentopf die Blumenpflege erleichtert.

Weiter mögliche Profile für Pflanzen, die sich hieraus ergeben haben:
- Monstera
- Basilikum
- Drachenbaum

### 10. Kannst du dir vorstellen aufwändige Pflanzen zu halten?

Auf einer Skala von 1 (Nein) bis 5 (Ja) war die Durchschnittsantwort 2,68. Insgesamt waren alle Antworten dabei mit einer Tendenz zu Nein.

Fazit:
Wir lassen aufwändige Pflanzen vorerst außer acht.

### 11. Wie viel Zeit pro Woche möchtest/kannst du aufwenden?

Der Großteil möchte nicht mehr als 60 Minuten pro Woche aufwenden. Die Mehrheit sogar nicht mehr als 30 Minuten.
- weniger als 30 min (18)
- 30 min bis 60 min (13)

Fazit:
Da fast alle nicht mehr als 60 Minuten pro Woche aufwenden möchten, sollten wir nicht zu häufig Benachrichtigungen/Erinnerungen schicken, da diese sonst schnell nervig werden.

### 12. Würdest du die Pflege (teilweise) automatisieren?

Meiste Antworten:

### 1. Ja (22) 2. Nein (10) 3. Ein bisschen (9)

Fazit:
Automation lohnt sich für etwa 75% der Befragten ("Ja" & "Ein bisschen")

### 13. Warum würdest du die Pflege (teilweise) automatisieren wollen?

Die häufigsten Antworten lassen sich unter vier Oberbegriffen zusammenfassen:
- Vergesslichkeit
- Abwesenheit
- Vereinfachung
- Zeitersparnis

Anmerkung:
Insgesamt 30 Antworten

Fazit:
Ein Feature für die Abwesenheit im Urlaub ist viel gewünscht. Dies würde eine automatisches Bewässerungssystem erforden.

### 14. Warum würdest du die Pflege nicht automatisieren wollen?

Die meistgenannten Gründe gegen eine Automatisierung sind:
- Pflanzen als Hobby / beruhigende Beschäftigung
- Kosten
- Technik als Problemfaktor
- Aufwand lohnt sich nicht

Anmerkung:
Insgesamt 10 Antworten
15. & 16. Was stellst du dir als Smarten Blumentopf vor? & Welche Funktionen wären dir wichtig?

Die meistgenannten Funktionen sind:
- Steuerung über mobiles Endgerät
- Überprüfung von Feuchtigkeit, Temperatur & Licht plus Feedback
- Versorgung der Pflanze (Gießfunktion)
- Selbstständigkeit der Pflanze
- Pflanzenprofileinbindung

Anmerkung:

### 41 Antworten

Fazit:
Ein automatisches Bewässerungssystem und eine Anzeige für das Feedback sind als viel gefragtes Feature erwünscht.

### 17. Wie möchtest du mit dem Blumentopf interagieren?

Häufigste Antworten:

### 1. App (33) 2. Display (17) 3. Leds (16) 4. Button (11) 5. Web Interface & Sonstiges (0)

Fazit:
Die meisten möchten eine App zur Bedienung. Als nächstes folgen Display und LEDs zur Visaulisierung.
Ein Web-interface ist nicht erwünscht.

Anmerkung:
Ein Web-Interface wäre universeller einsetzbar/kompatibel und für uns einfacher zu realisieren.
Eventuell konnten sich viele nichts Konkretes unter einem Web-Interface vorstellen.

### 18. Hältst du einen Smarten Blumentopf für sinnvoll?

Häufigste Antworten:

### 1. Ja (24) 2. Ja, aber nicht für mich (11) 3. Nein (2)

Fazit:
Auch wenn ein paar der Befragten den smarten Blumentopf für sich selber nicht als sinnvoll erachten, haben nur zwei Personen mit "Nein" geantwortet.
Ein smarter Blumentopf lohnt sich also auf jeden Fall, wenn auch nicht für jeden.

### 19. Für welche Pflanzen ist der Topf nutzbar?

Größtenteils wurde hier geantwortet mit "pflegeintensiven Pflanzen" und "alle Pflanzen". Jedoch waren die Antworten so durcheinander, dass wir keine eindeutige Schlussfolgerung ziehen können.

### 20. Wieviel würdest du für einen smarten Blumentopf bezahlen?

Der Durchschnitt liegt hier bei etwa 30 €

Fazit:
Der oben genannte Wert liegt 5 € über unseren ursprünglichen Überlegungen.

### 21. Möchtest du vorgefertigte Pflanzenprofile zur Auswahl haben?

Meiste Antworten:

### 1. Ja, aber bearbeitbar (28) 2. Ja (9) 3. Nein (4)

Fazit:
Wir sollten auf jeden Fall Profile einbinden und diese auch personalisierbar machen.

### 22. Weitere Ideen?

- Smartheit sollte nicht erkennbar sein
- Der Topf sollte Dicht sein
- ansprechende Optik / schlichtes Design
- verschiedene Farben (naturtöne)

Fazit:
Die Dichtheit haben wir auch schon in unseren Überlegungen notiert und die restlichen Ideen kann man im späteren Designprozess mit einbinden.

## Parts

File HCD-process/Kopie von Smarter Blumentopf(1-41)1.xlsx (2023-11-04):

ID | Startzeit | Fertigstellungszeit | E-Mail | Name | Zeitpunkt der letzten Änderung | Wie alt bist du? | Wo wohnst du? | Besitzt du Pflanzen? | Welche Pflanzen besitzt du? | Wie viele Blumentöpfe besitzt du? | Wo stehen deine Blumentöpfe? | Wie groß sind deine Blumentöpfe? | Vergisst du manchmal deine Pflanzen zu gießen? | Welche Pflanzen würdet ihr euch noch für euer Heim wünschen? | Kannst du dir vorstellen, aufwändige Pflanzen zu halten? | Wieviel Zeit in der Woche würdest du in die Pflanzenpflege stecken? | Würdest du die Pflege deiner Pflanze gerne (teilweise) automatisieren? | Warum würdest du es gerne (teilweise) automatisieren? | Warum würdest du es nicht (teilweise) automatisieren? | Was stellst du dir unter einem "Smarten Blumentopf" vor? | Was für Funktionen wären dir wichtig bei einem Smarten Blumentopf? | Wie wäre für dich eine Interaktion am praktischsten? | Hältst du einen smarten Blumentopf für sinnvoll? | Für welche Pflanzen würdet ihr den Blumentopf verwenden? | Wie viel würdest du für einen smarten Blumentopf in € bezahlen? | Hättest du gerne einen Smarten Blumentopf mit vorgefertigte Pflanzenprofile zum Auswählen? | Habt ihr noch Ideen oder weitere Anregungen?
3 | 2023-10-27 08:07 | 2023-10-27 08:11 | anonymous |  |  | 21 | in einer Wohnung | Nein |  |  |  |  |  | Ein paar Blumen | 2 | <30 Minuten | Ja | Ich vergesse sie immer oder bin zu depressiv, und dann sterben sie mir immer weg und ich bin noch depressiver :( |  | Einen Blumentopf den ich über ein mobiles endgerät “steuern” kann? | Automatisches gießen der Pflanze, vielleicht auch automatisches Düngern, richtig crazy wären Analyse der Erd-Qualität und so | App;Status LED`s;Button; | Ja, definitiv | Blumen und andere Topfpflanzen:) 🪴 | 30 | Ja, ich möchte die Profile aber auch gerne bearbeiten können | Nö, will einfach kein Mörder mehr sein :(
4 | 2023-10-27 08:07 | 2023-10-27 08:12 | anonymous |  |  | 21 | in einem Haus | Ja | Fleischfressenepflanze | 0 | Bad; |  | Ja, manchmal | Monstera | 1 | <30 Minuten | Ja | Weil es dann einfacher wird |  | Ein Topf der die Feuchtigkeit, Temperatur und Lichtverhältnissen misst und anzeigt, ob alles in Ordnung ist | Feuchtigkeitsmesser | Button;App;Status LED`s; | Ja, definitiv | Fleischfressenepflanze | 20 | Ja, ich möchte die Profile aber auch gerne bearbeiten können
5 | 2023-10-27 08:07 | 2023-10-27 08:15 | anonymous |  |  | 26 | in einer Wohnung | Ja | Gemüse, Kräuter, Grünlilie | 5 | Fensterbank;Auf dem Boden; | <10cm Durchmesser;10cm<20cm Durchmesser; | Ja, manchmal | Orchideen, sonstige Zimmerpflanzen | 2 | 30 Minuten <1 Stunden | Vielleicht ein wenig | Nicht immer ans gießen denken müssen, nicht da sein |  | Kann gießen und düngen, ist Teuer und super empfindlich | Sagt Bescheid, wenn Pflanze zu trocken oder zu nass - kann gießen und düngen, optimal: Schädlinge erkennen | Status LED`s;App; | Ja, aber nicht für mich persönlich | Zimmerpflanzen | 30 | Ja, ich möchte die Profile aber auch gerne bearbeiten können | Drinnen vs draußen - wie empfindlich darf die Technik sein? Ästhetisch, robust UND günstig wäre toll
6 | 2023-10-27 08:09 | 2023-10-27 08:15 | anonymous |  |  | 58 | in einem Haus | Ja | Topfpflanzen | 7 | Fensterbank;Auf dem Boden;Küche; | 10cm<20cm Durchmesser;20cm<50cm Durchmesser; | Ja, manchmal | Keine weiteren, die vertrocknen bei uns | 2 | gar keine Zeit | Ja | Ich vergesse sie immer |  | Einen Topf der die Pflanze versorgt und den Standort der Pflanzen überprüft | Wasser Temperatur Sonne Dünger | App;Button; | Ja, definitiv | Basilikum, Orchidee... | 10 | Ja
7 | 2023-10-27 08:07 | 2023-10-27 08:16 | anonymous |  |  | 22 | in einer Wohnung | Ja | Zimmerpflanzen, Balkonpflanzen, gemüsepflanzen, Beeren, Obstbäume... | 25 | Fensterbank;Nachttisch;Küche;Bad;Schlafzimmer;Balkon; | Alle Größen; | Sehr selten | Man kann nie genug haben. (Keine Kakteen) | 5 | 2 Stunden < 5 Stunden | Nein |  | Ich habe Pflanzen, damit ich mich um sie kümmern kann | Pflanze kaufen und für immer in eine Ecke stellen können, ohne sich drum zu kümmern | Gießen... wenn man mal in den Urlaub fahrt muss man keine Angst haben, dass sie sterben. Aber Gießen dann angepasst auf Jahreszeit und pflanzenart | App; | Ja, aber nicht für mich persönlich | Zimmerpflanzen die ausgiebig gegossen werden müssen | 30 | Ja, ich möchte die Profile aber auch gerne bearbeiten können
8 | 2023-10-27 08:24 | 2023-10-27 08:37 | anonymous |  |  | 21 | in einer WG | Ja | Verschiedenste (zu viele) | 10 | Fensterbank;Nachttisch;Auf dem Boden;Schlafzimmer;Schreibtisch, Schrank, Sekretär; | <10cm Durchmesser;10cm<20cm Durchmesser;20cm<50cm Durchmesser; | Nein, so gut wie nie | String of turtles | 4 | <30 Minuten | Nein |  | Meine Pflanzen sind so schon teuer genug | Ein Hilfsmittel, was mich darauf hinweist, wie ich meine Pflanze optimal versorge [am Besten, ohne dass ich wirkliche alles voreinstellen muss, aber es doch könnte]. | Das Sich-Richten nach verschiedenen Pflanzenarten. Pflanzenerkennung (vllt. durch Fotos?) | App;Button; | Das kommt sehr auf die Umsetzung und den Preis an. Er kann bestimmt für sehr komplizierte Pflanzen sinnvoll sein oder wenn man sich wirklich garnicht um die Pflanzen kümmern möchte. Zumeist habe ich aber einfach dieses Problem noch nicht und finde Pflanzen mit normalen Töpfen häufig schon recht teuer. | Für die teuersten und kompliziertesten im Raum. | 15 | Ja, ich möchte die Profile aber auch gerne bearbeiten können
9 | 2023-10-27 08:40 | 2023-10-27 08:43 | anonymous |  |  | 21 | in einem Haus | Nein |  |  |  |  |  | Kaktus | 2 | <30 Minuten | Ja | Zeitersparnis |  | Analysiert Pflanze/Erde | Gießen | Button; | Ja, aber nicht für mich persönlich | Kaktus | 30 | Ja, ich möchte die Profile aber auch gerne bearbeiten können
10 | 2023-10-27 08:41 | 2023-10-27 08:46 | anonymous |  |  | 29 | in einer Wohnung | Ja | Schnittlauch, Zimmerpflanze, und Beetpflanzen | 6 | Fensterbank;Balkon; | 10cm<20cm Durchmesser; | Ja, sehr oft | Frische Kräuter | 1 | gar keine Zeit | Ja | Vergesslichkeit und wenig Zeit |  | Kümmert sich alleine um gießen etc. | Kümmert sich alleine um gießen etc | App; | Ja, definitiv | Alle die ich habe | 15 | Ja, ich möchte die Profile aber auch gerne bearbeiten können
11 | 2023-10-27 08:39 | 2023-10-27 08:48 | anonymous |  |  | 25 | in einem Haus | Ja | Kakteen | 3 | Fensterbank; | <10cm Durchmesser; | Ja, sehr oft | Palmen | 3 | <30 Minuten | Ja | Um den Zeitaufwand zu reduzieren |  | Selbstständige Gies-Funktion | Selbstständige Überwachung des Feuchtigkeitsgehalts in der Blumenerde inkl. automatischen Abgleich mit dem Flüssigkeitsbedarf der jeweiligen Pflanze und eigenständige Gies-Funktion | App; | Ja, definitiv | Für alle, besonders aber für pflegeintensive Pflanzen | 20 | Ja, ich möchte die Profile aber auch gerne bearbeiten können
12 | 2023-10-27 08:42 | 2023-10-27 08:52 | anonymous |  |  | 21 | in einer Wohnung | Ja | Zimmerpflanzen (Pfennigbaum, Ficus, Aloe,...); Balkonpflanzen (Rosen, Wildblumen, Kapuzinerkresse,...) | 16 | Fensterbank;Balkon; | 20cm<50cm Durchmesser; | Sehr selten | Größere Pflanzen, wie Elefantenfuß oder Strelitzie | 4 | 2 Stunden < 5 Stunden | Nein |  | Ich mag es gerne mich um meine Pflanzen zu kümmern und finde die Beschäftigung beruhigend | Vielleicht eine Art Blumentopf der zu festgelegten Zeiten die Pflanze selbst bewässert oder festellen kann, dass die Erde trocken ist und dann bewässert | Bewässern | Status LED`s;Button;Display; | Ja, aber nicht für mich persönlich | Pflanzen die mehr Pflege brauchen und empfindlicher sind | 50 | Ja, ich möchte die Profile aber auch gerne bearbeiten können
13 | 2023-10-27 08:18 | 2023-10-27 08:56 | anonymous |  |  | 22 | in einer WG | Nein |  |  |  |  |  | Kräuter | 2 | <30 Minuten | Ja | Automatisierung ist die Zukunft |  | Durch eine Logik pflegt sich die Pflanze selber | Status abrufen können | Status LED`s;App; | Ja, definitiv | Kräuter | 30 | Ja, ich möchte die Profile aber auch gerne bearbeiten können
14 | 2023-10-27 09:07 | 2023-10-27 09:18 | anonymous |  |  | 22 | Zimmer im Wohnheim | Ja | Aloe Vera, Spinnenpflanze, Efeutute | 5 | Fensterbank;Schlafzimmer;Regal; | 10cm<20cm Durchmesser; | Ja, manchmal | Monstera Deliciousa, Efeu, Eucalyptus, mehr Efeututen, Bonsaibaüme! | 5 | <30 Minuten | Vielleicht ein wenig | Wenn man in den Semesterferien längere Zeit nicht da ist oder in den Urlaub fährt, wäre es praktisch wenn die Pflanzen nicht sterben |  | Genauso wie ein normaler nur mit mehr Technik die man aber nicht sieht, vielleicht so Messung von der Bodenfeuchtigkeit und Temperatur und irgendwie ein Mechanismus mit dem dann Wasser reingeleitet wird ab einer bestimmten, einstellbaren Bodenfeuchtigkeit. | Messen von Feuchtigkeit und Gießen | App; | Kommt auf die Umsetzung drauf an | Besonders große schöne und teure Pflanzen | 15 | Ja, ich möchte die Profile aber auch gerne bearbeiten können
15 | 2023-10-27 09:25 | 2023-10-27 09:29 | anonymous |  |  | 54 | in einem Haus | Ja | Tomaten gurken | 20 | Fensterbank; | 10cm<20cm Durchmesser; | Ja, manchmal | Palmen | 3 | 30 Minuten <1 Stunden | Nein |  | Lieber per hand | Topf mit Bewässerung | Selbstbewaesserung | Display; | Ja, aber nicht für mich persönlich | 5 | 2 | Nein ich möchte alles selber machen | Nein
16 | 2023-10-27 09:25 | 2023-10-27 09:34 | anonymous |  |  | 63 | in einem Haus | Ja | Blumen, Kräuter, | 10 | Fensterbank;Küche;Bad;Flur;Terrasse ; | 10cm<20cm Durchmesser;50cm<100cm Durchmesser; | Ja, sehr oft | Orchidee Kräuter alpenveillichen benjamin | 1 | 10 Minuten | Ja | Zeit |  | Ich kümmere mich um nichts werde erinnert | Erinnerungsfunktion für das Giesen, umtopfen, Düngen, mehr Licht, Gefahr von Schädlingen | Button;Display; | Ja, definitiv | Alle, aber die Optik ist auch wichtig | 8 | Ja | Der Topf muss unten dicht sein, damit ich ihn so auf die Fensterbank stellen kann, nicht erkennbar das er smart ist, ansprechende Optik vielleicht mit Farbauswahloption
17 | 2023-10-27 09:24 | 2023-10-27 10:12 | anonymous |  |  | 21 | in einer WG | Ja | Monsteras, Efeututen, Kakteen, Sukkulenten, Gummibaum, Palmen, String of Hearts, Orchidee, uvm. | 30 | Fensterbank;Auf dem Boden;Auf Kommoden, zwei Schränken und dem Schreibtisch; | <10cm Durchmesser;10cm<20cm Durchmesser;20cm<50cm Durchmesser;50cm<100cm Durchmesser; | Ja, manchmal | Ich hab erstmal genug :) | 5 | 30 Minuten <1 Stunden | Vielleicht ein wenig | Weil ich manchmal wässern vergesse |  | Ehrlich gesagt, weiß ich es nicht, irgendwie sehe ich einen Topf mit ner kleinen Anzeige über Beschaffenheit der Erde usw. In meinem Kopf. | Erinnerungen über Wasserzustand, eventuell Infos über die Sonneneinstrahlung? | Display;App;Status LED`s; | Ja, aber nicht für mich persönlich | Für aufwendigere Dramaqueens, die bei einem Tag zusätzlich wässern alle Blätter abschließen | 25 | Ja, ich möchte die Profile aber auch gerne bearbeiten können
18 | 2023-10-27 10:10 | 2023-10-27 10:15 | anonymous |  |  | 21 | in einer WG | Ja | So eine Sukkulente lol | 1 | Bücherregal; | <10cm Durchmesser; | Ja, sehr oft | So hängende sind cool | 2 | <30 Minuten | Ja | Weil die bei mir sonst sterben |  | Ein Topf der essenzielle Dinge wie das bewässern übernimmt, mir bescheid gibt ob die Pflanze an Platz X genug Licht bekommt, und eventuell spezielle düngemittel vorschlägt | Bewässerung, Düngung, informationen zu Licht, Feuchtigkeit, etc. | App;Status LED`s; | Ja, definitiv | Sukkulenten, Kakteen, Hängepflanzen | 60 | Ja, ich möchte die Profile aber auch gerne bearbeiten können
19 | 2023-10-27 09:27 | 2023-10-27 11:08 | anonymous |  |  | 21 | in einer WG | Ja | Hauspflanzen:} | 40 | Fensterbank;Auf dem Boden;Schlafzimmer; | <10cm Durchmesser;10cm<20cm Durchmesser;20cm<50cm Durchmesser; | Sehr selten | Mastera Thai Constellation | 4 | 1 Stunden < 2 Stunden | Ja | Um Tote zu vermeiden |  | Also entweder kommuniziert der Topf direkt mit mir (z.B. Gesicht??) Oder halt per App | Er sollte den Wasserbedarf, , evtl auch Temperatur und Luftfeuchtigkeit ermitteln können:) | Display;App;Status LED`s; | Ja, definitiv | Caletheas.. die sind a bissen schwierig | 20 | Ja, ich möchte die Profile aber auch gerne bearbeiten können
20 | 2023-10-27 11:20 | 2023-10-27 11:24 | anonymous |  |  | 24 | in einer Wohnung | Nein |  |  |  |  |  | Bonsai | 1 | gar keine Zeit | Ja | Kein grüner Daumen |  | Das er alles an notwendige Daten sammelt, dir überspielt und man Ende nur ausführt. (Düngen, Wässern usw.) | Ob die Pflanze genug Wasser hat | App; | Ja, definitiv | Bonsai | 50 | Ja
21 | 2023-10-27 13:20 | 2023-10-27 13:27 | anonymous |  |  | 62 | in einer Wohnung | Ja | Stauden, Sukkulenten, Bäume, Sträucher, Topfblumen | 25 | Fensterbank;draußen; | <10cm Durchmesser;10cm<20cm Durchmesser;20cm<50cm Durchmesser;50cm<100cm Durchmesser;und große; | Sehr selten | klimaresistente Pflanzen für den Garten, Fugenpflanzen für die Terrasse | 1 | 1 Stunden < 2 Stunden | Nein |  | Weil die Elektronik unzuverlässig ist und es viel Zeit dauert, alles einzurichten und bei Ausfall der Elektronik, alles neu einzurichten. | Ein Blumentopf mit Pflanze, der mit einem smarten Gerät verbunden ist, das die Bedürfnisse der Pflanze messen kann. | Feuchtigkeitsgrad der Erde im Topf | Display;App; | Ja, aber nicht für mich persönlich | Für Orchideen | 10 | Ja, ich möchte die Profile aber auch gerne bearbeiten können | Wie sieht es mit der smarten Pflege von ganzen Gärten aus? Hier besonders bezüglich des Nährstoffgehaltes des Bodens.
22 | 2023-10-27 14:25 | 2023-10-27 14:29 | anonymous |  |  | 21 | in einem Haus | Nein |  |  |  |  |  | Kakteen | 2 | 30 Minuten <1 Stunden | Ja | Um die Pflege einfacher zu macheb |  | selbstständige Versorgung der Pflanze | Dünger, Wasser in Zeitintervallen zuführen | App; | Ja, definitiv | Aufwendige Pflanzen | 25 | Ja, ich möchte die Profile aber auch gerne bearbeiten können
23 | 2023-10-27 15:08 | 2023-10-27 15:16 | anonymous |  |  | 26 | in einer Wohnung | Ja | Goldpalme, Efeu, Kaktus, Fikus, Grünlilie, Zimmeraralie | 8 | Fensterbank;Regal;Auf dem Boden;Küche;Schlafzimmer; | <10cm Durchmesser;10cm<20cm Durchmesser;20cm<50cm Durchmesser; | Ja, manchmal | Kokospalme | 4 | 30 Minuten <1 Stunden | Ja | Z.B. fürn Urlaub |  | Ein Blumentopf, der weiß wann die Pflanze Wasser braucht | Dass er anzeigt, wann man die Pflanze gießen müsste | App;Status LED`s; | Ja, definitiv | Alle | 50 | Ja, ich möchte die Profile aber auch gerne bearbeiten können
24 | 2023-10-27 15:08 | 2023-10-27 15:17 | anonymous |  |  | 24 | in einer Wohnung | Ja | Efeu, Grünlilie, Fikus, Kaktus, Goldpalme, Zimmeraralie | 8 | Fensterbank;Auf dem Boden;Küche;Schlafzimmer; | 10cm<20cm Durchmesser;<10cm Durchmesser; | Ja, manchmal | Kokospalme, Monstera | 5 | 30 Minuten <1 Stunden | Ja |  |  | Blumentopf mit Anzeigetafel | Anzeige Gießen, Düngen, Gesundheit der Pflanze | App;Status LED`s;Display; | Ja, definitiv | Alle | 75 | Ja, ich möchte die Profile aber auch gerne bearbeiten können
25 | 2023-10-27 15:11 | 2023-10-27 15:22 | anonymous |  |  | 72 | in einem Haus | Ja | Diverse Gartenpflanzen, Apfelbaum, Spalierobst usw | 10 | Im Garten ; | 10cm<20cm Durchmesser;20cm<50cm Durchmesser; | Ja, manchmal | Olivenbäumchen, Zitronenbäumchen | 2 | <30 Minuten | Ja | Aus Kostengründen |  | Einer der sich selbstständig gießt wenn er was braucht | Wassergabe | App; | Ja, definitiv | Zierbäumchen, Kübelpflanzen | 40 | Ja, ich möchte die Profile aber auch gerne bearbeiten können | Leider nein
26 | 2023-10-27 15:26 | 2023-10-27 15:30 | anonymous |  |  | 20 | in einer WG | Ja | Kakteen, Bambus, Monstera | 5 | Fensterbank;Schlafzimmer; | 10cm<20cm Durchmesser;<10cm Durchmesser; | Vorher öfter mal, hab jetzt ne App die mich erinnert | - | 3 | 30 Minuten <1 Stunden | Nein |  | Weil es mir Spaß macht | Ein Blumentopf, der mich an die Pflege der Pflanzen erinnert | Selbst gießen, wenn man mal länger weg ist | App;Status LED`s; | Ja, definitiv | Monstera | 30 | Ja, ich möchte die Profile aber auch gerne bearbeiten können
27 | 2023-10-27 18:08 | 2023-10-27 18:17 | anonymous |  |  | 24 | in einer Wohnung | Ja | Grünlilien, Elefantenfuß, Kakteen | 11 | Fensterbank;Küche;Schlafzimmer;Im Regal; | 10cm<20cm Durchmesser;<10cm Durchmesser;20cm<50cm Durchmesser; | Ja, manchmal | Orchideen | 1 | <30 Minuten | Vielleicht ein wenig | Zum wohl der Pflanze |  | Ein normaler topf mit messfühlern und einspritzpumpe für wasser und Nährstoffe | Vorallem die Gießfunktion, also messung der Trockenheit des Substrats | Display; | Ja, aber nicht für mich persönlich | Teure tropische pflanzen | 20 | Ja, ich möchte die Profile aber auch gerne bearbeiten können | Nein
28 | 2023-10-27 18:24 | 2023-10-27 18:39 | anonymous |  |  | 25 | in einer Wohnung | Ja | Drachenbaum, Birkenfeige, Gummibaum, aloe vera, Minze | 5 | Fensterbank;Küche;Wohnzimmer ; | 10cm<20cm Durchmesser; | Ja, manchmal | Palmen | 5 | 30 Minuten <1 Stunden | Ja | Das ist grade gut für Leute (wie mich) die nicht so einen Grünen Daumen haben. So könnte man sich auch pflegeintensivere Pflanzen holen und würden überleben. |  | Das der Topf die Pflanze kennt und dementsprechend zeigt wann sie Wasser oder Dünger oder so braucht. | Bewässerung Info. Wann und wieviel Wasser. Wenn die Erde schimmel, eine Info geben was man da am besten macht (auf die Pflanze abgestimmt) | Display;App;Status LED`s; | Ja, definitiv | Alle | 30 | Ja, ich möchte die Profile aber auch gerne bearbeiten können
29 | 2023-10-27 18:45 | 2023-10-27 18:52 | anonymous |  |  | 25 | in einer WG | Ja | Monsterra, bei den anderen weiß ich’s leider nicht | 5 | Fensterbank;Auf dem Boden; | 10cm<20cm Durchmesser;20cm<50cm Durchmesser; | Sehr selten | Yucca Palme | 4 | 30 Minuten <1 Stunden | Nein |  | lohnt für den Aufwand nicht | Automatisches Gießsystem, Analyse was der Pflanze fehlt | Automatisches Gießen | Status LED`s;Display; | Nein, ist nicht sinnvoll | Teure | 25 | Ja
30 | 2023-10-27 18:47 | 2023-10-27 18:55 | anonymous |  |  | 24 | in einer WG | Ja | Kaffeepflanz, Pilea, Calathea, PACHIRA AQUATICA | 6 | Auf dem Boden;Schlafzimmer; | 20cm<50cm Durchmesser;<10cm Durchmesser; | Ja, manchmal | Basilikum, Kaktus, Monsterra | 3 | <30 Minuten | Ja | Damit ich nicht mehr daran denken muss |  | Bewässert die Pflanze eigenständig über einen längeren Zeitraum | Bewässerung | Button;App; | Ja, definitiv | Alle | 17.99 | Ja, ich möchte die Profile aber auch gerne bearbeiten können | Erweiterung eines bestehend Blumentopfes; Reinigungssystem (Stichwort Kalk)
31 | 2023-10-27 19:05 | 2023-10-27 19:14 | anonymous |  |  | 55 | in einem Haus | Ja | Kaktus, Kaffee, Ananaspflanze, Pilea, Tanne, Basilikum, Minze, Herzblattpflanze | 33 | Fensterbank;Auf dem Boden;Küche;Bad;Flur; | <10cm Durchmesser;10cm<20cm Durchmesser;20cm<50cm Durchmesser; | Nein, so gut wie nie | Palme | 1 | <30 Minuten | Nein |  | Keine Ahnung von Technik; keine Investition; keine Innovation | Bewässerung, Licht | Bewässerung, Licht, Umtopfen | Button;Status LED`s;Display; | Nein, ist nicht sinnvoll | Keine | 0 | Nein ich möchte alles selber machen
32 | 2023-10-28 21:02 | 2023-10-28 21:07 | anonymous |  |  | 19 | in einer Wohnung | Ja | Zimmerpflanzen | 18 | Fensterbank;Auf dem Boden;Schlafzimmer; | <10cm Durchmesser;10cm<20cm Durchmesser; | Sehr selten | Bin gerade zufrieden | 2 | 30 Minuten <1 Stunden | Nein |  | Weil ich nicht so viele Pflanzen habe, dass ich das benötigen würde und weil ich es mag meine Pflanzen zu pflegen | automatisierte Bewässerung | Angabe ob die Pflanze Wasser braucht/ Schädlinge hat | Display;App; | Ja, aber nicht für mich persönlich | Für keine meiner eignen, aber vielleicht für aufwendigere pflanzen | 20 | Nein ich möchte alles selber machen
33 | 2023-10-29 14:39 | 2023-10-29 14:47 | anonymous |  |  | 23 | in einer WG | Nein |  |  |  |  |  | Succulenten, Leuchterblumen | 1 | <30 Minuten | Ja | - gleichmäßigere, optimierte Bewässerung |  | - Messung der Erdfeuchtigkeit + Status Anzeige | - Ablesbarkeit des Wasserstands, - Selbstständige Bewässerung | Display; | Ja, definitiv | Kleine Pflanzen (kleine Topfgrößen)/schnelle Austrocknungsgefahr | 20 | Ja, ich möchte die Profile aber auch gerne bearbeiten können
34 | 2023-10-29 18:29 | 2023-10-29 18:43 | anonymous |  |  | 27 | in einer Wohnung | Ja | Grünpflanzen, Sukkulenten, Gemüse, Beeren, Kräuter, ... | 30 | Fensterbank;Auf dem Boden;Küche;Bad;Flur;Schlafzimmer;Balkon; | <10cm Durchmesser;10cm<20cm Durchmesser;20cm<50cm Durchmesser; | Ja, manchmal | blühende Pflanzen | 4 | 1 Stunden < 2 Stunden | Vielleicht ein wenig | Damit das Gießen nicht vergessen wird |  | Einen Topf, der sich selbst bewässert, wenn die Pflanze Wasser braucht | Erkennen von Wassermangel oder -überschuss, Bewässerungssystem oder Melder zum Gießen | Button;App;Status LED`s; | Ja, für Menschen, die Pflanzen haben möchten, aber keine Zeit in die Pflege investieren möchten/können | für Pflanzen, die oft und regelmäßig gegossen werden müssen | 20 | Ja, ich möchte die Profile aber auch gerne bearbeiten können
35 | 2023-10-29 18:59 | 2023-10-29 19:04 | anonymous |  |  | 28 | in einer Wohnung | Ja | Zimmerpflanzen GemüsePflanzen Kräuter | 100 | Fensterbank;Auf dem Boden;Küche;Flur; | 50cm<100cm Durchmesser;20cm<50cm Durchmesser;10cm<20cm Durchmesser;<10cm Durchmesser; | Sehr selten | Keine | 5 | 30 Minuten <1 Stunden | Nein |  | Weil es keine Herausforderung mehr wäre | Ein schlauer Blumentopf der messen kann was die Pflanze braucht und entsprechend versorgt | Selbstständig Gießen nach Bedarf und düngen | App; | Ja, aber nicht für mich persönlich | Pflege intensivere Pflanzen | 50 | Nein ich möchte alles selber machen
36 | 2023-10-29 19:49 | 2023-10-29 19:53 | anonymous |  |  | 26 | in einer Wohnung | Ja | Monsteras, Wasserlilie | 6 | Fensterbank;Auf dem Boden;Schlafzimmer; | 10cm<20cm Durchmesser;<10cm Durchmesser; | Ja, manchmal | Noch mehr monsteras | 4 | <30 Minuten | Ja | Weniger Aufwand, höhere Wahrscheinlichkeit das es den Pflanzen gut geht. |  | Ein unauffällige Möglichkeit meine Pflanzen automatisch mit Wasser zu versorgung | Automatische Wasserversorgung | App;Button;Display; | Ja, definitiv | Alle Zimmerpflanzen | 20 | Ja, ich möchte die Profile aber auch gerne bearbeiten können
37 | 2023-10-29 19:53 | 2023-10-29 20:05 | anonymous |  |  | 62 | in einem Haus | Ja | Verschiedene Zimmerpflanzen, viele Gartenpflanzen | 5 | Auf dem Boden;Fensterbank;Bad; | 20cm<50cm Durchmesser; | Ja, manchmal | Alpenveilchen | 2 | <30 Minuten | Vielleicht ein wenig | Dann wären sie immer optimal versorgt |  | Topf meldet, wenn den Pflanzen etwas fehlt | Sollte Alarm schlagen, wenn Wasser oder Dünger fehlt. | Status LED`s;App; | Ja, aber nicht für mich persönlich | Zitruspflanzen | 20 | Ja | Nein
38 | 2023-10-29 20:08 | 2023-10-29 20:39 | anonymous |  |  | 26 | in einer Wohnung | Ja | Kakteen, Sansiveria, Orchidee, Palmenart | 10 | Fensterbank;Auf einem Regal mitten im Zimmer; | Von allem was dabei; | Ja, sehr oft | Katzenfreundliche (z.B. Gräser) | 2 | <30 Minuten | Ja | Damit man die Pflanzen garnicht erst vernachlässigen kann - bessere Übersicht. r |  | Kontrolliert bzw. misst vielleicht die Wassermenge und die Beschaffenheit der Erde, sowie die Temperatur o.ä.. | Einfache Bedienbarkeit und gute Übersicht über alle Pflanzen, wo die doch in ver. Räumen platziert sind. | App; | Ja, definitiv | Für alle außer Sukkulenten/einfachen Pflanzen wo die Bedingungen nicht so entscheidend sind. | 20 | Ja | Messung Sonneneinstrahlung/Temperatur
39 | 2023-10-29 20:32 | 2023-10-29 20:50 | anonymous |  |  | 31 | in einer Wohnung | Ja | 3 Zimmerpflanzen | 6 | Küche;Bad;Wohnzimmer Schrank ; | 10cm<20cm Durchmesser;20cm<50cm Durchmesser; | Nein, so gut wie nie | Eine große Boden Pflanze | 2 | 30 Minuten <1 Stunden | Vielleicht ein wenig | Manchmal geht mir eine Pflanze ein ohne das ich vergesse sie zu Gießen da wüsste ich gerne, was die Pflanze hat. |  | Einen mit Sensoren der in der Blumen Erde fühlen kann was der Pflanze fehlt. | Eine Anzeige oder meldung für den Zustand und einen alarm fürs Gießen. | App;Display; | Ja, definitiv | Alle möglichen... | 10 | Ja | Am besten noch mit selbstbewässerung für die zeit wenn man im Urlaub ist. Mit Pumpe und Wasserbehälter wo der Blumentopf von alleine mit der Bewässerung beginnt bei Bedarf.
40 | 2023-10-30 00:12 | 2023-10-30 00:19 | anonymous |  |  | 23 | in einer WG | Nein |  |  |  |  |  | Möchte aktuell keine Pflanzen mehr | 2 | <30 Minuten | Ja | Zeitersparnis |  | Kleiner Alltagshelfer im Umgang mit Pflanzen | Wässern, Ausrichtung nach Sonne / Schatten | Display;App; | Ja, definitiv | Alle | 10 | Ja, ich möchte die Profile aber auch gerne bearbeiten können | Ansprechendes, modernes, aber schlichtes Design in Naturtönen
41 | 2023-10-30 10:02 | 2023-10-30 10:13 | anonymous |  |  | 21 | in einer Wohnung | Ja | Gummibaum, Sukkulenten | 3 | Fensterbank;Nachttisch; | <10cm Durchmesser;10cm<20cm Durchmesser; | Ja, manchmal | Kräuter | 3 | 30 Minuten <1 Stunden | Vielleicht ein wenig | Damit man entspannter in den Urlaub fahren kann, ohne jemanden zu brauchen, der die Pflanzen pflegt |  | Einen Blumentopf, der die Bedürfnisse der Pflanze erkennt (z.B. Wasser oder mehr Licht) und dem entsprechend dem Benutzer sagt was er machen soll (z.B. gießen oder zum Licht stellen). | Überwachende Funktion; Anzeige was der Pflanze fehlt | App; | Ja, definitiv | Für die Pflanzen die am meisten Arbeit machen. | 100 | Ja, ich möchte die Profile aber auch gerne bearbeiten können
42 | 2023-11-01 10:53 | 2023-11-01 11:04 | anonymous |  |  | 26 | in einer Wohnung | Nein |  |  |  |  |  | Drachenbaum, Birkenfeige | 2 | <30 Minuten | Vielleicht ein wenig | Meine Pflanzen sind bis jetzt immer gestorben. |  | Ein Topf, der weiß, wie viel Wasser, Nährstoffe, usw., welche Pflanze braucht und vllt Speicher hat, um die entsprechenden Mengen hinzugeben zu können. | Wasser und Nährstoffversorgung. Nicht Batteriebetrieben. | App;Display; | Ja, vielleicht. | Etwas schwerer zu pflegende Pflanzen. | 50 | Ja
43 | 2023-11-01 11:04 | 2023-11-01 11:18 | anonymous |  |  | 61 | in einem Haus | Ja | Kräuter und Zimmerpflanzen | 5 | Fensterbank;Küche; | 10cm<20cm Durchmesser; | Ja, manchmal | Große Blattpflanzen | 1 | gar keine Zeit | Ja | Ich habe keinen grünen Daumen (gieße zu viel) |  | Automatische Bewässerung auch während meiner Abwesenheit | Automatische Bewässerung auch während meiner Abwesenheit, Meldung von Schäden z.b. zu viel Sonnenschein oder Zugluft oder Schädlingen oder Nährstoffmangel | App; | Ja, definitiv | Große teure Zimmer- und Balkonpflanzen | 30 | Ja | Gerne auch Balkonpflanzen
 |  |  |  |  |  | 30.82926829 |  |  |  |  |  |  |  |  |  |  |  |  |  |  |  |  |  |  | 28.12170732

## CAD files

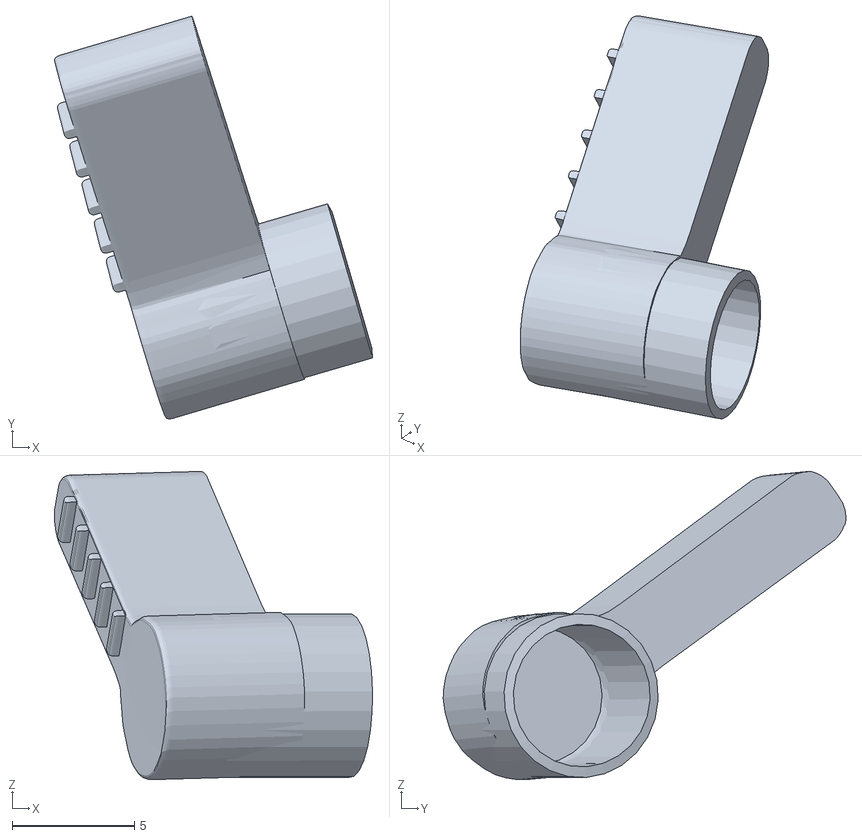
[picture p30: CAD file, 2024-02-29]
3dModel/STL_Dateien/TemometaIcon.stl
13.0 x 16.5 x 12.6

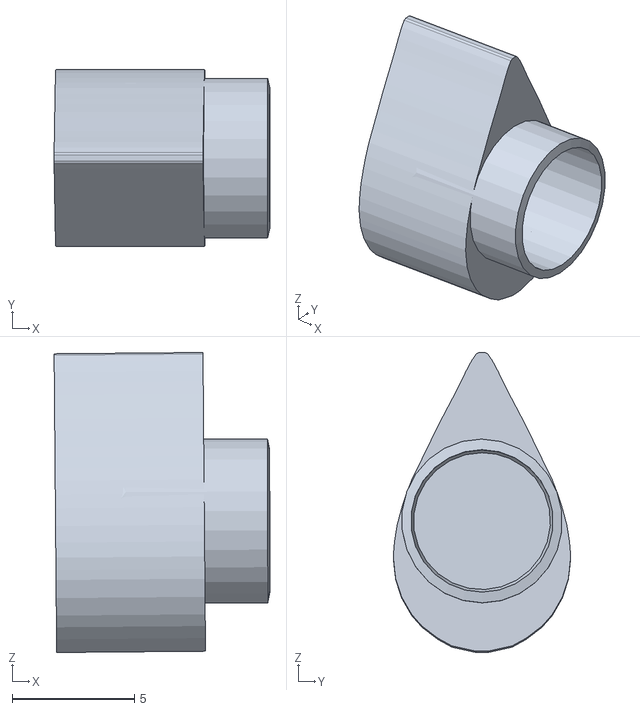
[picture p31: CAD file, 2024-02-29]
3dModel/STL_Dateien/TropfenIcon.stl
8.83 x 7.26 x 12.3

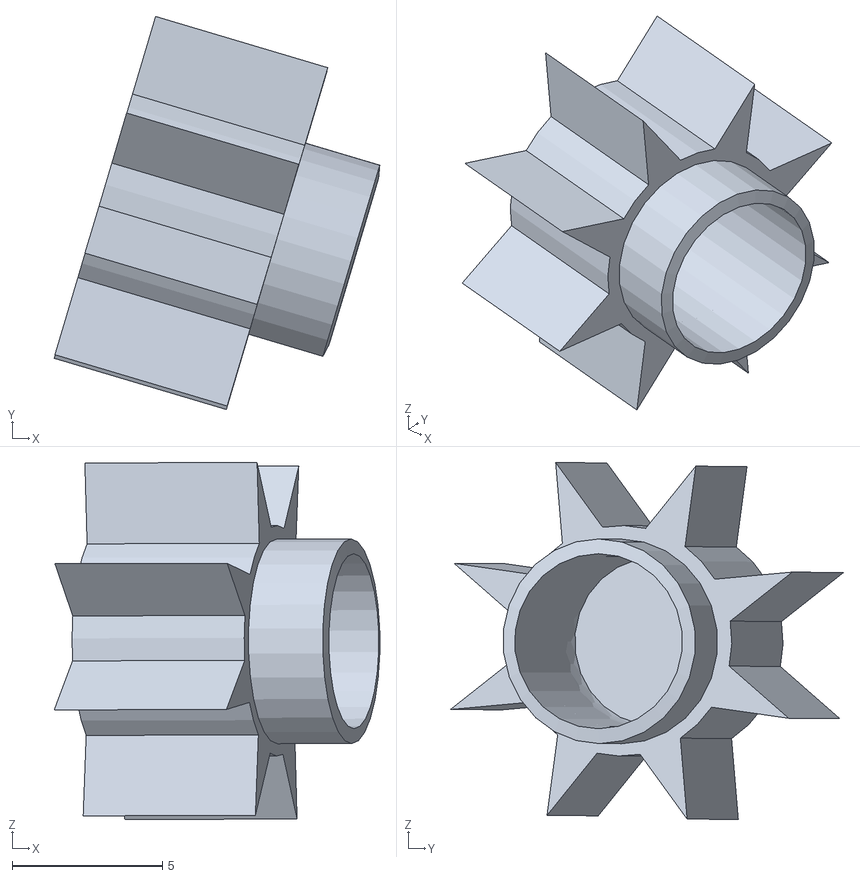
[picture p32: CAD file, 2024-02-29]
3dModel/STL_Dateien/SonneIcon.stl
10.8 x 13.1 x 11.9

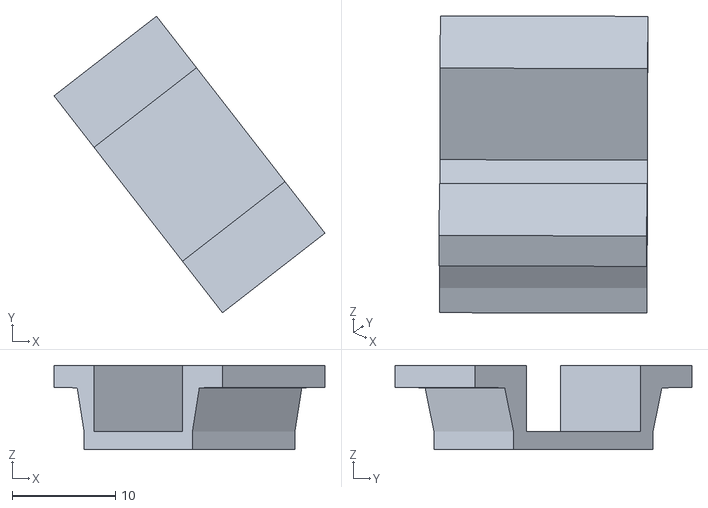
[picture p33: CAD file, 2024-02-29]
3dModel/STL_Dateien/Buttonhalterung.stl
26.3 x 28.8 x 8.16

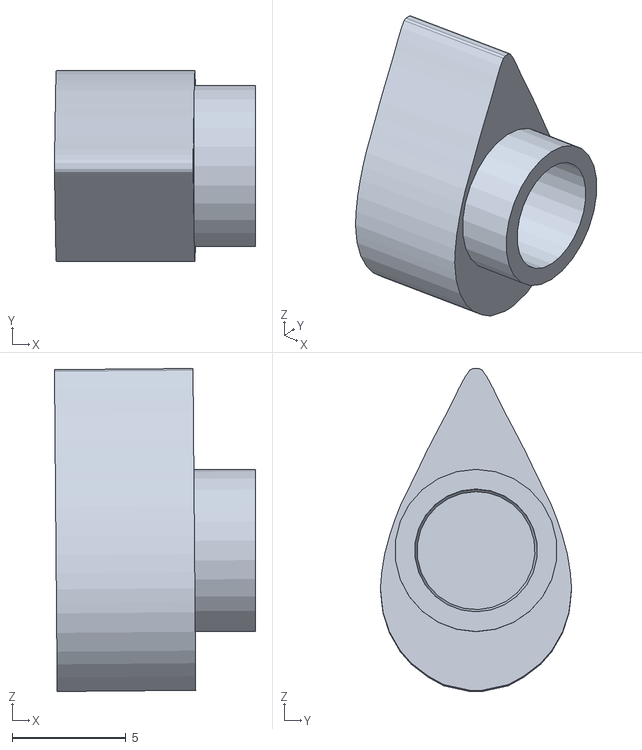
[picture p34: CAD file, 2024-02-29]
3dModel/STL_Dateien/Tropfenicondual.stl
8.84 x 8.41 x 14.2

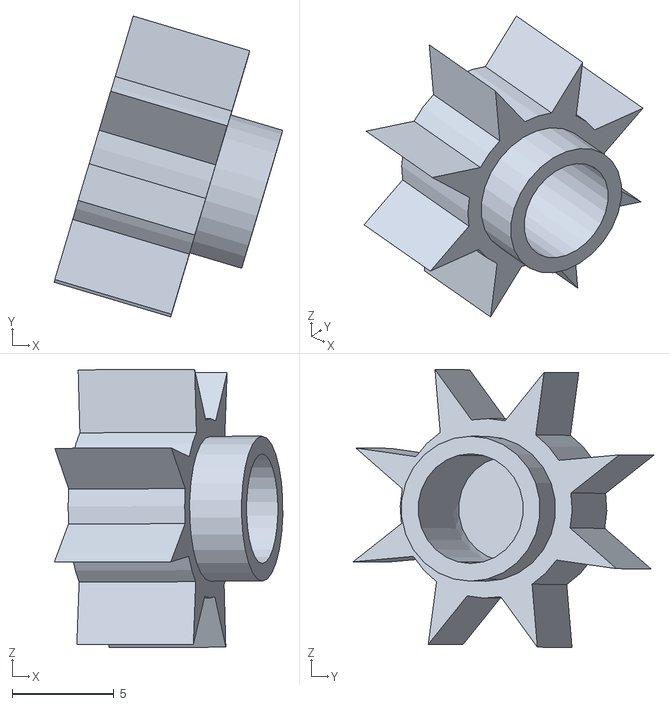
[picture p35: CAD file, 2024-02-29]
3dModel/STL_Dateien/sonneicondual.stl
11.2 x 14.8 x 13.7

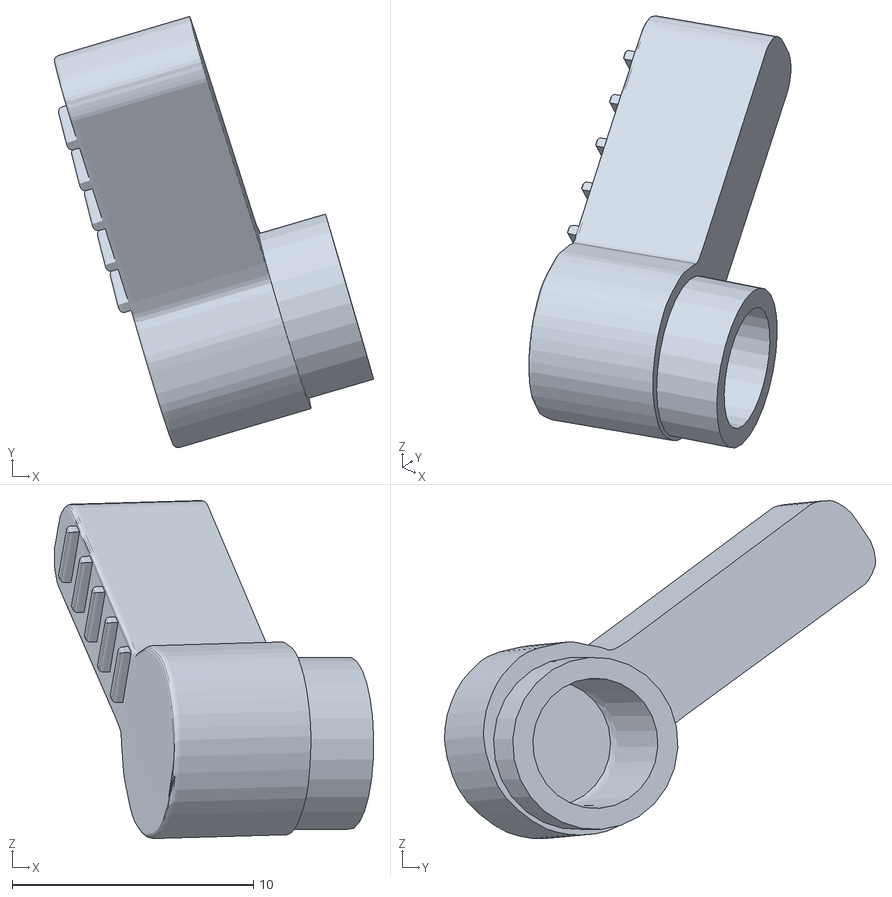
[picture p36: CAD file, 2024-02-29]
3dModel/STL_Dateien/temometaicondual.stl
13.2 x 17.9 x 14.0

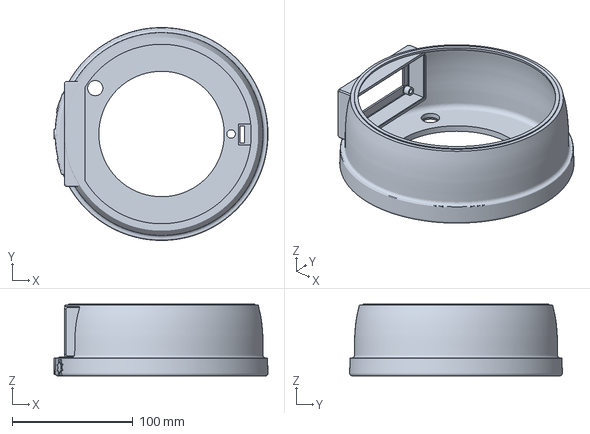
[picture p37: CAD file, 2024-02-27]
3dModel/STL_Dateien/Topfzweigeteiltoben.3mf
177.5 x 176.5 x 59.7 mm

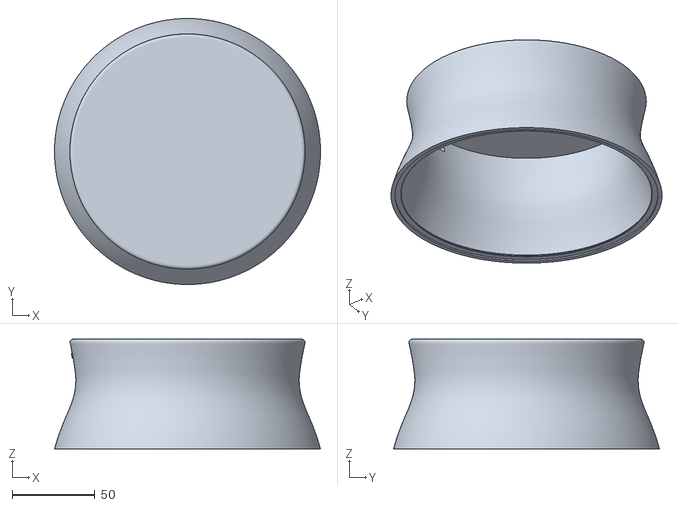
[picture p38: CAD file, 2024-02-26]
3dModel/STL_Dateien/Topfzweigeteiltunten.stl
160.4 x 160.4 x 66.2

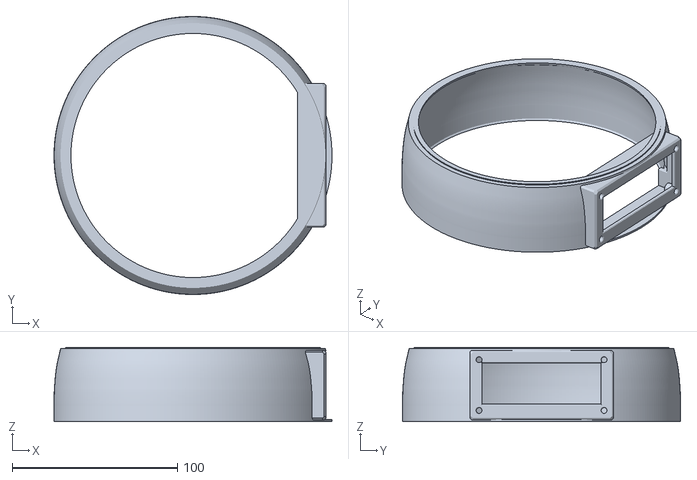
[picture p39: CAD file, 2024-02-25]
3dModel/STL_Dateien/TopfObenUnterteil.stl
168.4 x 168.4 x 44.8

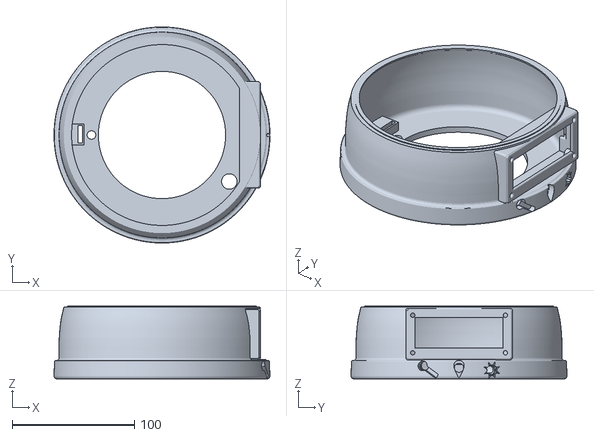
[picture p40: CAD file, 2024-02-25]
3dModel/STL_Dateien/TopfOben.stl
176.5 x 176.5 x 59.5

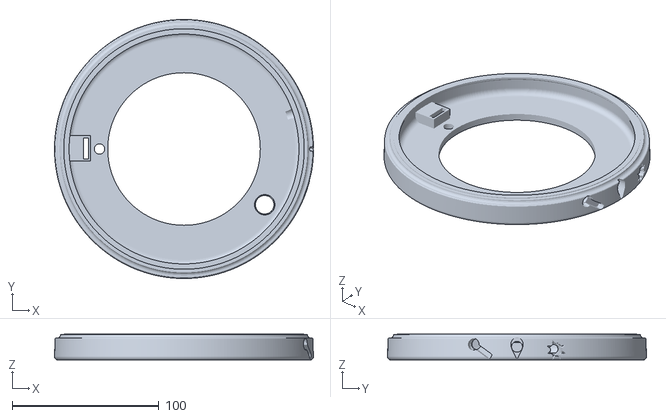
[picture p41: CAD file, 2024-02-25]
3dModel/STL_Dateien/TopfDreigeteiltObenOberteil.stl
176.5 x 176.5 x 17.7

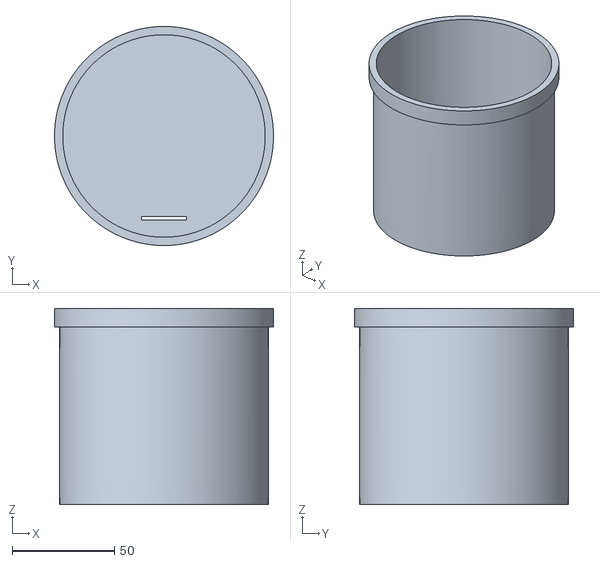
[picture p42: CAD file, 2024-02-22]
3dModel/STL_Dateien/innenTopf.stl
107.3 x 107.3 x 96.1

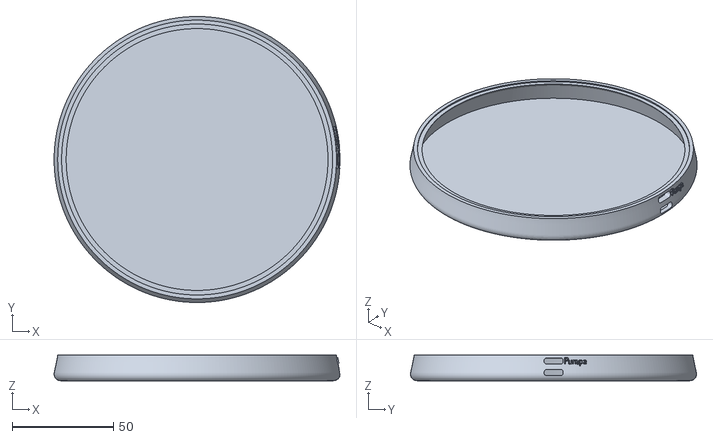
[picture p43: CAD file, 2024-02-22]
3dModel/STL_Dateien/TopfDreigeteiltBoden.stl
141.0 x 141.1 x 12.6

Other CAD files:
3dModel/STL_Dateien/TopfDreigeteiltMitte.stl
3dModel/STL_Dateien/TopfDreigeteiltOben.stl
Archiv/3dModelArchiv/andere größe/Boden.stl
Archiv/3dModelArchiv/Schraubenunten.stl
3dModel/STL_Dateien/Topfzweigeteiltoben.stl
3dModel/Topf4.blend
Archiv/3dModelArchiv/Gehäuseoben.stl
Archiv/3dModelArchiv/Gehäuseunten.stl
Archiv/3dModelArchiv/Topf1.blend
Archiv/3dModelArchiv/Topf2.blend
Archiv/3dModelArchiv/Topf3.blend
Archiv/3dModelArchiv/andere größe/Gehäuseoben.stl
Archiv/3dModelArchiv/andere größe/Gehäuseunten.stl
Archiv/3dModelArchiv/andere größe/InnenTopf.stl
Archiv/3dModelArchiv/boden1.stl
Archiv/3dModelArchiv/innentopf.stl

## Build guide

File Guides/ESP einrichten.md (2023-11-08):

# ESP32 How to start Guid
## Hinweise:
- Achtung, Code nicht direkt auf dem ESP Speichern!!! (begrenbzte Anzahl an Schreibzyklen)
- Wenn der ESP32 nicht vom PC erkannt wird: anderes Kabel Testen, Silicon Labs Treiber installieren, PC neustarten

 ## 1. ESP32 mit (Win/Mac) verbinden
 - Thonny IDE installieren [hier](https://thonny.org/)
 - Silicon Labs Treiber installieren [hier](https://www.silabs.com/developers/usb-to-uart-bridge-vcp-drivers?tab=downloads)

   
 - Rechner neustarten!!!
 - Überprüfen ob Rechner ESP32 erkennt
   - Windows:
     - "[Win]()" + "[r]()" drücken, "[cmd]()" eintippen und "[OK]()"
     - Dann "[mode]()" eingeben und auf die ausgabe warten

       
     - Jetzt ESP32 per USB Kabel mit Rechner verbinden und noch einmal "[mode]()" 
     - Darauf achten welcher COM Port Neu ist (wie im Beispielbild)
      
       
       
   - MacOS:
     - ESP32 per USB Kabel mit Rechner verbinden
     - Thonny IDE Öffnen
     - Weiter zu 2. Firmware aufspielen/ ESP32 Flashen

 ## 2. Firmware aufspielen/ ESP32 Flashen
 ### 2.1 Thonny Options
 - In Thonny "Run"->"Select interpreter"
       
    

- "MicroPython (ESP32)" Auswählen
      
  

### 2.2 Richtigen COM Port auswählen/ 
 - Windows: Hier den oben erfassten COM Port auswählen

    
   
 - MacOS: Hier den "CP2102N USB to UART Bridge Controller" auswählen
    Bildschirmfoto 2023-11-06 um 10 46 52

- Für Win/Mac "Install or update MicroPython"

    

### 2.3 Install MicrtoPython (esptool)
- Com Port/"CP2102N USB to UART Bridge Controller" auswählen und Kontrollerspezifikationen auswählen wie im Bild

  

- "Install" klicken
- Wenn Error, Boot Button des ESP32 kurz vor "Install" drücken

    

### 2.4 Pyrhon auf ESP32 spielen und ausführen
- Eine main.py erstellen "File"->"New"
- MicroPython Interpreter für ESP32 Auswählen

  

- Beispielcode einfügen:
  
        print("Scanning for WiFi networks, please wait...")
        print("")
  
        import network
        sta_if = network.WLAN(network.STA_IF)
        sta_if.active(True)
  
        authmodes = ['Open', 'WEP', 'WPA-PSK' 'WPA2-PSK4', 'WPA/WPA2-PSK']
        for (ssid, bssid, channel, RSSI, authmode, hidden) in sta_if.scan():
          print("* {:s}".format(ssid))
          print("   - Auth: {} {}".format(authmodes[authmode], '(hidden)' if hidden else ''))
          print("   - Channel: {}".format(channel))
          print("   - RSSI: {}".format(RSSI))
          print("   - BSSID: {:02x}:{:02x}:{:02x}:{:02x}:{:02x}:{:02x}".format(*bssid))
          print()

  - Ausführen mit "Run" -> "Run current Interpreter" oder "F5" auf dem ESP32 ausführen
    


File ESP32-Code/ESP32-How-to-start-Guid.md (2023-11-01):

# ESP32 How to start Guid

 ## Firmware aufspielen
 - Thonny installieren [hier](https://thonny.org/)
 - ESP32 an PC anschließen
 - In Thonny "Run"->"Select interpreter"
       
    

### Thonny options
- "MicroPython (ESP32)" Auswählen
      
  

- richtigen COM Port auswählen (welcher ist der richtige? [hier]())

    

- "Install or update MicroPython"

    

### Install MicrtoPython (esptool)
- Com Port auswählen und Kontroller auswählen wie im Bild

  

- "Install" klicken & Boot Button des ESP32 kurz drücken, danach "close"

    

  ### Pyrhon auf ESP32 spielen und ausführen
- Eine main.py erstellen "File"->"New"
- MicroPython Interpreter für ESP32 Auswählen

  

- Beispielcode einfügen:
  
        print("Scanning for WiFi networks, please wait...")
        print("")
  
        import network
        sta_if = network.WLAN(network.STA_IF)
        sta_if.active(True)
  
        authmodes = ['Open', 'WEP', 'WPA-PSK' 'WPA2-PSK4', 'WPA/WPA2-PSK']
        for (ssid, bssid, channel, RSSI, authmode, hidden) in sta_if.scan():
          print("* {:s}".format(ssid))
          print("   - Auth: {} {}".format(authmodes[authmode], '(hidden)' if hidden else ''))
          print("   - Channel: {}".format(channel))
          print("   - RSSI: {}".format(RSSI))
          print("   - BSSID: {:02x}:{:02x}:{:02x}:{:02x}:{:02x}:{:02x}".format(*bssid))
          print()

  - Ausführen mit "Run" -> "Run current Interpreter" oder "F5" auf dem ESP32 ausführen
    


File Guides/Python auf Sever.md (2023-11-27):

# Dokumentation: Einrichtung und Starten von Python Flask im Venv

1. Auf das Venv auf dem Server in dem Python mit Flask läuft zugreifen: 
```bash
bash:
source myflaskenv/bin/activate
```
2. App.py im venv starten:
```bash
bash:
gunicorn -w 4 -b 192.168.178.59:5000 app:app
```
3. Beenden über Control + C

4. Verlassen von venv:
```bash
bash:
deactivate
```

5. gucken was auf port 5000 so läuft:

```bash
bash:
sudo lsof -i :5000
```

6. alle prozesse auf port 5000 töten:

```bash
bash:
sudo killall gunicorn
```

7. Auf app.py zugreifen im venv:
```bash
bash
nano app.py
```
(Speichern in Nano mit Control + X und dann Y, Enter)

8. Code der app.py für Flask auf dem Server:
```python
Python:
from flask import Flask, request
import json
import datetime

app = Flask(__name__)

@app.route('/Blumentopf/upload_data', methods=['POST'])
def upload_data():
    if request.method == 'POST':
        try:
            data = request.get_json()  # JSON-Daten von ESP32 erhalten
            if data:  # Überprüfen, ob gültige JSON-Daten erhalten wurden
                current_time = datetime.datetime.now().strftime("%Y-%m-%d_%H-%M-%S")
                file_name = f'/var/www/blumentopfbackend/Database/received_data_{current_time}.json'  # Speicherort und Dateiname
                with open(file_name, 'w') as file:  # Daten in eine neue Datei schreiben
                    json.dump(data, file, indent=4)
                return "Daten erfolgreich empfangen und gespeichert"
            else:
                return "Ungültige JSON-Daten erhalten"
        except Exception as e:
            return f"Fehler beim Verarbeiten der Daten: {str(e)}"
    else:
        return "Nur POST-Anfragen erlaubt"

if __name__ == '__main__':
    app.run(host='192.168.178.59', port=5000)  # Anpassen des Ports und der Host-Adresse nach Bedarf
```

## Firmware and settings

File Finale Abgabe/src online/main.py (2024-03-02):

#main
from Control import Control
import utime
import gc
import micropython


#setup
gc.collect()
micropython.mem_info()
control = Control()         # Initialisierung des MVC

#Auskommentiert für Standalone Demo HIT
print('Setup Wifi')
control.setupWifi()         # Wifi setup


startTime = utime.ticks_ms()            # Var fürs speichern der Startzeit vom Programm 
sensorInterval = 5000                   # Gibt an in welchem Interval Sensoren ausgelesen werden sollen 
sensorTime = startTime + sensorInterval # Timet den zeitpunkt fürs erneute auslesen der Sensoren 
serverThreshold = 5                     # Anzahl wie oft Werte gelesen werden sollen, vor Durschnittsbrechnung und Uploaud 
endTime= startTime + 600000             # um das Programm zu beenden, in dem fall nach 5min
running = True                          # startet den loop


##Variablen für Pumpensteuerung
pumpCheckInterval = 10000 #Intervall in dem überprüft wird ob wasser benötigt wird
pumpStatus = False #Pumpenstatus
pumpTime = startTime + pumpCheckInterval
pumpInterval2 = 2000 #Intervall in dem die Pumpe an ist
pumpTime2 = 0



#___________Loop__________#
while running:
   
    if control.btnColor.value():        # Button Prüfung Ob 0 oder 1
        control.view.printAllData()     # gieb Alle Sensor daten aus
        gc.collect()
    
    if utime.ticks_ms() > sensorTime:						# Auslesen der Sensoren
        print(control.btnWater.value())
        sensorData = control.allSensors.readAll()           # Ließt die methode fürs auslesen der sensoren 
        control.model.lightLog.append(sensorData[2])        # Hinzufügen des Lichtsensorwerts zum Log
        control.model.temperatureLog.append(sensorData[1])  # Hinzufügen des Temperaturewerts zum Log
        control.model.soilLog.append(sensorData[0])         # Hinzufügen des Bodenfeuchtigkeitssensorwerts zum Log
        
        control.setCurrentValues()                          # Aktualliersierung der Log Daten! 
        control.compareData()                               # Die Methode vergleicht die aktuellen Sensorwerte mit den Grenzwerten aus der json
        
        sensorTime = utime.ticks_ms() + sensorInterval      # Aktuallisierung SensorTime für den nächsten Zeitpunkt für Auslesung
        gc.collect()

    elif utime.ticks_ms() > pumpTime and control.btnWater.value() == 1:                         #Überprüfen ob Pumpe aktiviert werden soll                          #wenn ESP Offline, aber average array voll ist, dann mach average und Clear log
        packLen = 5
        averageSoilLog = control.model.currentValues["moisture"] 							# Brechnung Durchschnittswert für soilLogprofile = self.model.profileData[0] # aktives profil
        minSoil = control.model.profileData[0]["boundaries"]["moisture"]["min"]               # mindest Wert an Moisture bis Pumpe Aktiviert wird
        if averageSoilLog <= int(minSoil):
            control.pump.on()
            pumpStatus = True
            pumpTime2 = utime.ticks_ms() + pumpInterval2
        pumpTime = utime.ticks_ms() + pumpCheckInterval


    if pumpStatus == True and utime.ticks_ms() > pumpTime2 and control.btnWater.value() != 0:
        control.pump.off()
        pumpStatus = False
        pumpTime2 = utime.ticks_ms() + pumpInterval2

    logSize = len(control.model.lightLog)                   # gibt logSize die Anzahl der bisher im Licht-Log gespeicherten Datenpunkte an

    if logSize == serverThreshold and control.model.isWifiConnected: # Prüft ob anzahl der werte auch serverThreshold = 6 enspricht.
        packLen = 5
        averageLightLog = control.calcAverage(control.model.lightLog, packLen)              # Brechnung Durchschnittswert für lightLog
        averageTemperatureLog = control.calcAverage(control.model.temperatureLog, packLen)  # Brechnung Durchschnittswert für temperatureLog
        averageSoilLog = control.calcAverage(control.model.soilLog, packLen)                # Brechnung Durchschnittswert für soilLog
        
        print("Server Upload steht an!")
        print("Versuche, folgende Daten hochzuladen:", [averageLightLog, averageTemperatureLog, averageSoilLog]) # ausgabe server 
        
        newPrototype = control.server.getPrototype()   # Ruft das Prototyp-Objekt vom Server ab
        if newPrototype:                               # aktualisier interne Variablen mit den erhaltenen Daten und gibt eine Liste mit diesen Daten zurück.
            control.model.prototypData = newPrototype  # Füllt aktuallisierte daten in model.prototypData
        
        print(control.model.profileData)
        print(control.model.prototypData)
        
        #if control.model.prototypData != "{}":
          #  if control.model.profileData[1] != control.model.prototypData[1]:   # wenn die daten vom Profil nicht = die vom Proto sind
        control.setupServerData() 
        print(control.model.profileData)
        print("Neues Profil:", control.model.profileData[0]["name"])    # Ausgabe neues Profiel wurde Geladen

        control.server.addMeasurement(averageTemperatureLog, averageLightLog, averageSoilLog) #Fügt die durchschnittlichen Messwerte dem Server hinzu
        
        control.model.lightLog = []         # Leerung des Arrays 
        control.model.temperatureLog = []   # Leerung des Arrays 
        control.model.soilLog = []          # Leerung des Arrays 

        
    #if utime.ticks_ms() > endTime: # wenn der timer bei der entTime angekommen ist stoppe den Loop
        #running = False
        
#print("Saved the day")
#Sensoren Intervall (alle 5-10 sekunden)

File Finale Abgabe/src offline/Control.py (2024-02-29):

from Server import Server
from Model import Model
from View import View
from AllSensors import AllSensors
from Pump import Pump 
import machine
import utime

class Control:
    def __init__(self):
        
        self.model = Model()
        
        self.allSensors = AllSensors(self.model.soilData, self.model.tempData, self.model.lightData) # Instanzierung der Atribute von den jeweili
        self.view = View(self.model)
        self.server = Server(self.model.ssid, self.model.wifiPw, self.model.profileUrl, self.model.prototypUrl, self.model.uploadUrl, self.model.webUser, self.model.webPw)
        self.running = False # brauchen wir nur für deu methode startByPress()
        self.btnColor = machine.Pin(self.model.btnData["dpin"], machine.Pin.IN)
        self.btnWater = machine.Pin(34, machine.Pin.IN)
        self.pump = machine.Pin(32, machine.Pin.OUT)
        self.btnStat = False
        self.leds = {
            "light": machine.Pin(self.model.ledPins["light"], machine.Pin.OUT),
            "temperature": machine.Pin(self.model.ledPins["temperature"], machine.Pin.OUT),
            "moisture": machine.Pin(self.model.ledPins["moisture"], machine.Pin.OUT)
            }
        self.blink_speed_ms = 500
        self.model.profileData = self.model.load_json(self.model.localFileName)
        
        
         
    def setupWifi(self): #method to send Test Data to server and pulls data from the server
       # if self.model.isWifiConnected == False: #TestMemo
        self.server.connectWifi() #TestMemo
        self.model.isWifiConnected = True #TestMemo (komplett weg)
        self.setupServerData() #TestMemo
        #self.model.isWifiConnected = self.server.sta_if.isconnected()#TestMemo
        #print(self.server.getRemote())
        #print(self.server.setTestDataToServer())
        #print(self.server.getRemote())     
        
        
    def setupServerData(self): # Abruf Proto daten und Speicher im Model
        
#         if self.model.isWifiConnected:
#             print("Jahuga")
#             print(self.server.getPrototype())
#             print(self.server.getProfile())
#             self.model.prototypData = self.server.getPrototype()
#             self.model.status = {'light': self.model.prototypData[0]['sensors']['light']['status'],
#                                  'moisture': self.model.prototypData[0]['sensors']['moisture']['status'],
#                                  'temperature': self.model.prototypData[0]['sensors']['temperature']['status']}
#         else:
#             print("Not Connected to Wifi")


        if self.model.isWifiConnected:
            print("Jahuga")
            prototype_data = self.server.getPrototype()
            profile_data = self.server.getProfile()
            print(profile_data)
            print(prototype_data)
            if prototype_data is not None and profile_data is not None:
                self.model.profileData = profile_data #TestMemo (komplett weg)
                self.model.prototypData = prototype_data
                self.model.status = {
                    'light': self.model.prototypData[0]['sensors']['light']['status'],
                    'moisture': self.model.prototypData[0]['sensors']['moisture']['status'],
                    'temperature': self.model.prototypData[0]['sensors']['temperature']['status']
                }
            else:
                print("Error: Failed to retrieve server data.")
        else:
            print("Error: Not Connected to Wifi")
        
        #print(self.model.prototypData)
        print(self.model.status) # nur zum test
        
        #TestMemo
#         self.model.profileData = self.server.getProfile()
#         print(self.model.profileData)
#         if self.model.profileData != self.model.load_json(self.model.localFileName) and self.model.profileData != False and self.model.profileData is not None :
#             self.model.save_json_if_changed(self.model.localFileName, self.model.profileData)
#         
#         if self.model.profileData == False :
#             if self.model.load_json(self.model.localFileName) is not None:
#                 self.model.profileData = self.model.load_json(self.model.localFileName)
#                 print("if")
#             else :
#                 self.model.profileData = [None,'None']
#                 print("else")
#             
#         print(self.model.profileData)
         
        
    def sensorTemperatureTest(self): #method to test the readings of TemperatureSensor
        print("Angeschlossen an: ",self.model.tempData)
        self.allSensors.readTemperatureSensor() #fuehrt die auslesung über die vererbung aus 
        print("Temperature", self.allSensors.temperaturSensorValue)
        
    def sensorLightTest(self): #method to test the readings of LightSensor
        print("Angeschlossen an: ",self.model.lightData)
        self.allSensors.readLightSensor()
        print("Light:", self.allSensors.lightSensorValue)
        
    def sensorSoilTest(self): #method to test the readings of SoilSensor
        self.allSensors.readSoilSensor() #setzt neuen wert in var der Classe AllSensors alle measureDuration im abstand
        #if self.allSensors.soilSensorValue != None:#wenn nicht None returnt wird (passiert wenn die letzte Messung nicht mindestens measureDuration (z.b. 5000 ms) her ist)
            #print("Bodenfeuchtigkeit: ",self.allSensors.soilSensorValue)
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

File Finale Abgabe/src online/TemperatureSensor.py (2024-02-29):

import machine, onewire, ds18x20, time

class TemperatureSensor:
    def __init__(self, tempData): #btn_pin
        self.ds_pin = machine.Pin(tempData['dpin']) # pin für Sensor
        self.ds_sensor = ds18x20.DS18X20(onewire.OneWire(self.ds_pin)) # Kominikation mit Sensor
        self.roms = self.ds_sensor.scan() #Suche nach DS18B20-Sensoren
        self.running = False # Maybe muss das true sein(noch nicht sicher)
    

    def readTemperature(self): #Funktion ließ die Temperatur 
        self.ds_sensor.convert_temp() #Umwandlung (koventierung) der werte in Temperatur werte
        time.sleep_ms(750) #pause würde ich empfehlen 
        for rom in self.roms: # solange self.roms werte ließt
            temperature = self.ds_sensor.read_temp(rom) # temperatur = die gelesenen Koventierten werte
            return temperature

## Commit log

2023-10-12 Android App Test für Firebase und Push
2023-10-22 Sensoren datei
2023-10-31 Esptool & Firmware für den ESP32
2023-10-31 Joa sagen wir mal so, sieht nicht gut für Apple aus
2023-11-01 Okay ka bin in ESP32 drin aber kann keine datein ausführen lol
2023-11-01 Create ESP32-How-to-start-Guid.md
    So können das auch andere verstehen
2023-11-01 Wokwi Simulationen LEDs
    zwei Testsimulationen zum Betrieb von LEDs
2023-11-04 Moisture Sensor
2023-11-04 Soil Sensor Test
2023-11-05 Save to say the Moisture Sensor Works kinda,
    Genaueres Kalibrieren ist für alle Bodenfeuchtigkeitssensoren nötig, aber das wann anders evtl. am, Dienstag
2023-11-06 Auswertung Umfrage
    Hier ist die Zusammenfassung der Auswertung unserer Umfrage
2023-11-08 Okay auf Windows Läuft die Kalibrierung
2023-11-08 Korrektur der map_range, da sonst werde rauskommen die keinen sinn ergeben :D
2023-11-13 Temperaturfühler
2023-11-13 Fühler Temperatur klasse
2023-11-14 Fast finaler Temperatursensor
    das was wir bei der Sitzung am 14.11 gemacht haben
2023-11-18 Test für Pumpe & OLED Display
    Kleine Einbindungstest für Pumpe und Display
2023-11-19 Update Temperatur
2023-11-21 app.py die auf dem server liegt und mit Flask ausgeführt wird
2023-11-26 Nur zum Testen
    Habe eine Kopie des bisherig Codes genommen um in diesem arbeiten zu können ohne dabei den funktionierenden code zu zerstören :D
2023-11-26 Temperature Sensor might work but i could not test it. @NisVison might get it tom work
2023-11-26 2/3 Sensoren integriert
2023-11-27 Eventueller ersatz für Unseren Soil Sensor
2023-11-27 LightSensor @hystics bitte Testen & TemperaturSensor @NisVison bitte Testen
2023-11-27 bisschen schlechte bleleuchtung
    [Topf1.blend]
2023-11-29 lichtsensor halterunf ist drin
    [Topf1.blend]
2023-12-01 Klasse für Pumpe erstellt
2023-12-02 hab sleep aus der display klasse genommen und das der text egal wieviel komplett durch läuft
    [Topf1.blend]
2023-12-02 neue funktion : trennt zeilen
    "Feuchtigkeit:100%:Temperatur:12:Licht:www" beispiel string
2023-12-02 eue funktion : trennt zeilen
    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
2023-12-05 scrollen wenn mehr als 16
    [Topf1.blend]
2023-12-06 Ordner für die Website
2023-12-08 15 durchmesser
    [Topf2.blend]
2023-12-08 Wir schreiben das Hauptprogramm
2023-12-08 Wir Testen Licht
2023-12-09 upddate 3d
    [Topf2.blend]
2023-12-09 das model ist gesplittet
    [Gehäuseoben.stl, Gehäuseunten.stl, Topf3.blend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]
2023-12-11 Sensoren Funktioneren!!!!
2023-12-11 Update Server.py
    Erweiterung des Servers, AUCHTUNG beim Innstanzieren müssen jetzt noch 2 weitere sachen übergeben werden
2023-12-11 Update Control.py
    verbesserung des Auslesen der json datein
2023-12-11 update display pins
    [Topf3.blend]
2023-12-11 Control mit def compareData
    soll Sensorwerte mit min/max vergleichen -> noch zu testen
2023-12-12 gehäuse update
    [Gehäuseoben.stl, Topf3.blend]
2023-12-12 model update
    [Gehäuseoben.stl, Topf3.blend, innentopf.stl]
2023-12-12 Bodenfeuchtiggröße update
    [Boden.stl, Gehäuseoben.stl, Gehäuseunten.stl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]
2023-12-12 neue Funktionen
    noch an die richtige Stelle packen
2023-12-12 display leds und buttons implementiert
2023-12-13 Aufräumarbeiten
    [Kopie von Smarter Blumentopf(1-41)1.xlsx, app_bar_main.xml]
2023-12-13 Schöner Wohnen
    [Kopie von Smarter Blumentopf(1-41)1.xlsx]
2023-12-13 Bodenfreuchtigkeit🫠
2024-02-15 json speicher und lese funktionen
2024-02-15 json speichern des proflils geht hoffentlich
2024-02-22 Wifi Failsave, I2C Soil Sensor, WaterBTN
    [AllSensors.py, Control.py, SoilSensor.py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]
2024-02-22 Pumpe Testcode on pin 32
2024-02-22 Test Relay
2024-02-26 button vergessen
    [Topfzweigeteiltoben.stl]
2024-02-26 3D Aufgeräumt
    [Boden.stl, Gehäuseoben.stl, Gehäuseunten.stl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]
2024-02-26 letzte Runde umbenannt
    [SonneIcon.stl, TemometaIcon.stl, TopfDreigeteiltBoden.stl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]
2024-02-26 Blinkende LEDS
2024-02-28 TestMemo update
    Weiß nicht warum aber Machmal haben wir einen Fehlercode wegen dem Ram...
2024-02-28 Final Online und Offline
    Da die Offline Version Konstant funktioniert der separate Ordner
2024-02-29 Wir haben ein Video
2024-02-29 Pumpe Funktioniert fast
2024-02-29 Speicher crash behoben
    2 neue apis auf serverseite
    [Control.py, Model.py, Server.py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]
2024-02-29 Add files via upload
    definierte Frames im Miro Board zum finalen Stand
2024-02-29 Create Miro Board
2024-02-29 Miro Board Upload
2024-04-12 PDF PowerPoint
